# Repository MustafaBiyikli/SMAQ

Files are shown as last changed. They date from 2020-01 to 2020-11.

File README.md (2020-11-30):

## Smart monitoring of air quality with SMAQ
<p align="center">
    <a href="https://www.youtube.com/channel/UCAZxVj2a3wnd6SI2-zsWK3Q">
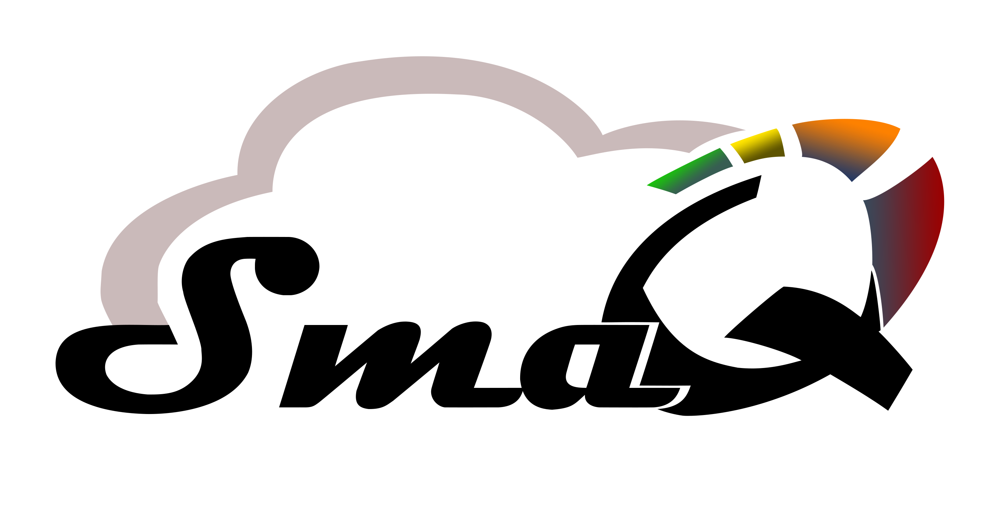
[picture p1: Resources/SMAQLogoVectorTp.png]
        
    </a>
</p>

SMAQ is designed to monitor the air quality in your chosen environment. The sampling rate can be adjusted from 1Hz to 10Hz. The ```./Software/Real-Time``` repo handles all low-level I2C communications and transmits the data via UDP (over port 65000) in real time as the data is sampled - to a JavaScript UDP receiver.
The UDP receiver places the data in a csv file which is then used to populate live DyGraphs and dashboard gauges for each parameter. The data is stored up to a week and follows a ring-buffer logic afterwards (storage time can be modified depending on the available disk space & user preference).
An express WebApp is launched from ```./Software/Website``` repo on port 8000 and can be accessed via url "ipofRaspberryPi:8000" within the same network.

- SMAQ is able to:
    - Sense:
        - Temperature: <b>-45 to 80 °C</b>
        - Pressure: <b>300 to 1250 hPa</b>
        - Humidity: <b>0 to 100 %</b>
        - Ambient Light: <b>0.25 to 16K lux</b>
        - Proximity: <b>1 to 200 mm</b>
        - Sound Levels: <b>0 to 100 %</b>
        - Carbon Monoxide: <b>1 to 1000 ppm</b>
        - Nitrogen Dioxide: <b>0.05 to 10 ppm</b>
        - Ammonia: <b>1 to 500 ppm</b>
    - Show the current conditions in your chosen environment with gauges
    - Store data up to a week, autozoom to 1wk | 5d | 3d | 24hr | 12 hr | 6hr | 1hr on WebApp
    - Send you immediate alerts via Email / Mobile Notifications and LEDs
    - Auto-remove your alerts when they are outdated
    - Output API data in JSON format
    - Display current conditions on an OLED display triggered by proximity
    
## PCB Design
The design files are in sub-directory ```./Hardware```
<p align="center">
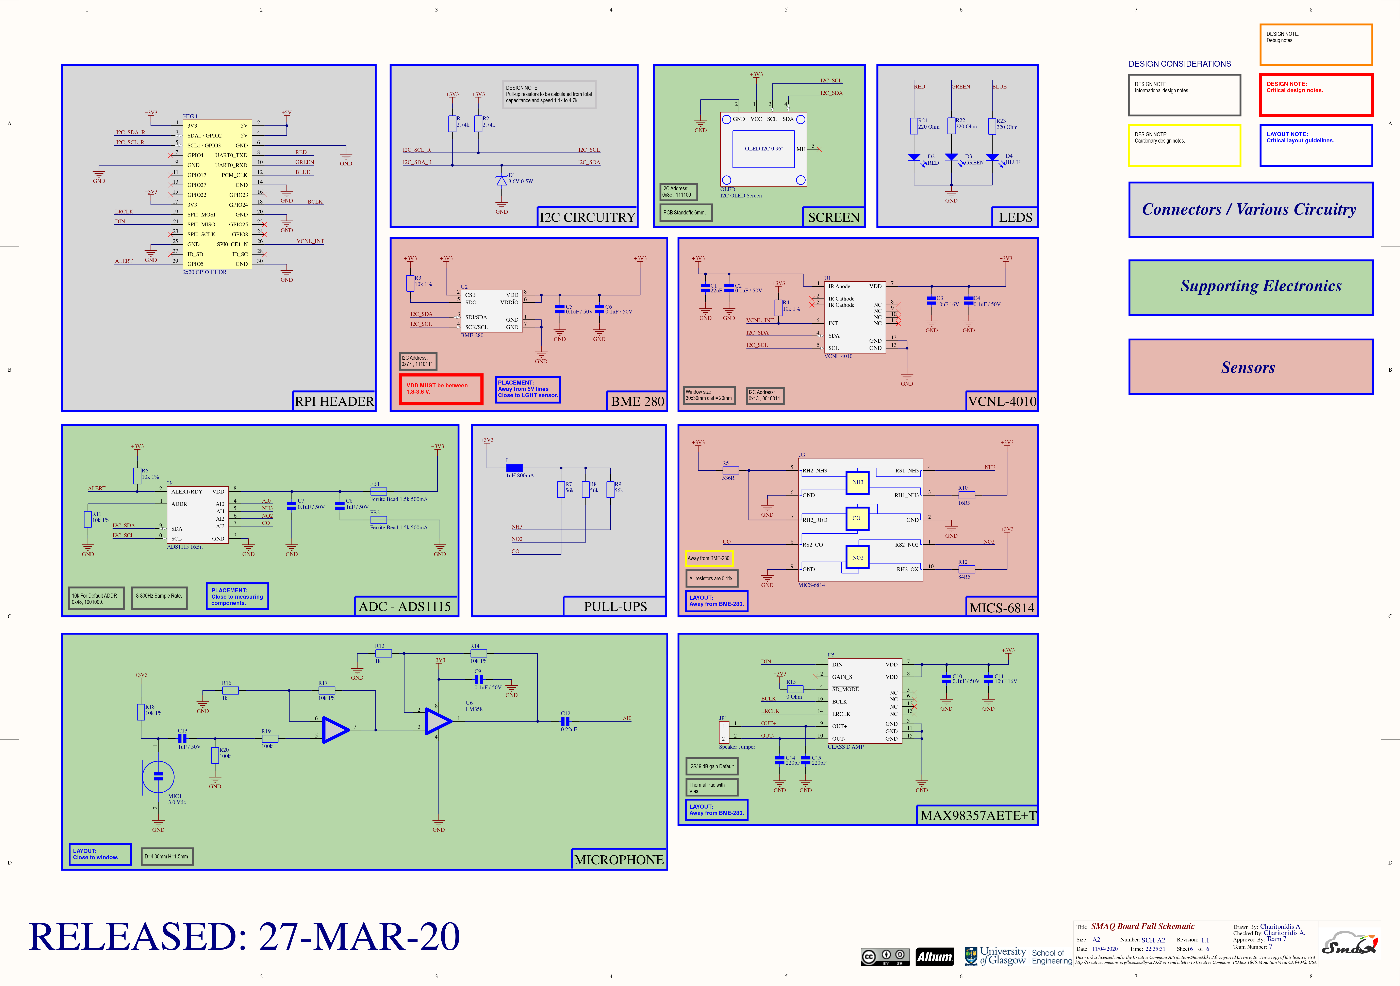
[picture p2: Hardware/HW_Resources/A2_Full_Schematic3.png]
    
</p>

## Pre-requisites
These are the packages required by SMAQ software, you need to have them installed on your raspberry Pi. They can be installed by running ```sudo apt-get install <package_name>```
```
gcc g++
cmake
git
npm
nodejs
```
Additionally, for receiving your alerts via email, you will need a <b>mailtrap</b> account for development and a <b>SendGrid</b> account for production. You will need to create your own ```config.env``` file and provide your keys. See ```./Software/Website/example-config.env.txt``` for a template.

## Building and running a demo
Clone and build the project with CMake
```
git clone https://github.com/MustafaBiyikli/SMAQ.git
cd SMAQ/Software/Real-Time
cmake .
make
```
Cmake will automatically check the I2C communication and run the necesarry tests when building the project. Test your harware by running a test.
```
./demo
```

This will start printing the sensor data onto your terminal. Press ```Enter``` to stop execution.

## Running the full WebApp
Start the cpp udp_transmitter in ```./Software/Real-Time``` as a background process:
```
./udp_transmit &
```

Then cd into ```../Website``` and run:
```
npm install
```

This will install the necessary NodeJS packages for the WebApp. Then, udp_receive.js and app.js needs to run as background processes. To do so, run the app in <b>production mode</b>:
```
npm run start:prod &
```
or:
```
node udp_receive.js &
node app.js &
```
You can now visit your SMAQ WebApp on url: "ipofRaspberryPi:8000"

## Killing the processes
To stop the background process, find their PIDs by:
```
ps ax
```
and kill each process by:

```
kill -HUP <PID>
```

## Viewing the WebApp without SMAQ
You can still view the WebApp without building the harware (using fake data), having cloned SMAQ into your local directory, you will need to start the app in <b>development mode</b>:
```
cd SMAQ/Software/Website
npm install
npm run start:dev &
```
or:
```
cd SMAQ/Software/Website
npm install
node fakeDataGenerator.js &
node app.js &
```
Killing the process follows the same logic as <b>Killing the process</b>

## Hardware - Main Components 

<p>
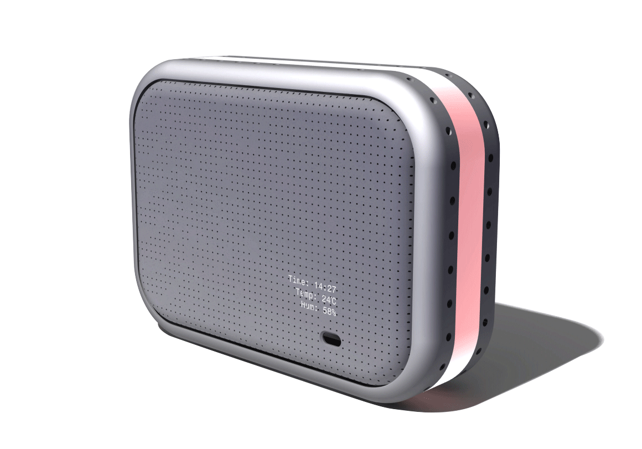
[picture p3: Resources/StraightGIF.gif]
    
</p>

See ```./Resources``` for packaging ideas and ```./Hardware``` for full details.

-   Raspberry Pi 3 Model B
-   PCB including:
    -   BME280 (Temperature, Pressure and Humidity Sensor)
    -   VCLN4010 (Proximity Sensor)
    -   SSH1106 (OLED Screen)
    -   MICS6814 (Gas Sensor)
    -   ADS1115 (ADC)
- 3D-printed casing and LED pipes

## Developers

<p align="center">
    <a href="https://github.com/Alexandros-Charitonidis">
        
    </a>
    &nbsp;  &nbsp;  &nbsp;  
    <a href="https://github.com/MustafaBiyikli">
        
    </a>
    &nbsp;  &nbsp;  &nbsp;  
    <a href="https://github.com/KasiaLenard">
        
    </a>
</p>

## Hosted Website

Vist SMAQ WebApp on: <b>https://team7smaq.github.io</b>
* Data you see here is randomly generated up to 1 minute as it is in development, however, the working principle is the same. You can have an idea of how SMAQ works without having to clone our repository.

## Introduction Video
<b>https://www.youtube.com/watch?v=mtV0Hn8jBWQ</b>

## Follow us on Social Media

<p align="center">
    <a href="https://www.facebook.com/SMAQ-Smart-Monitoring-of-Air-Quality-101030311565670">
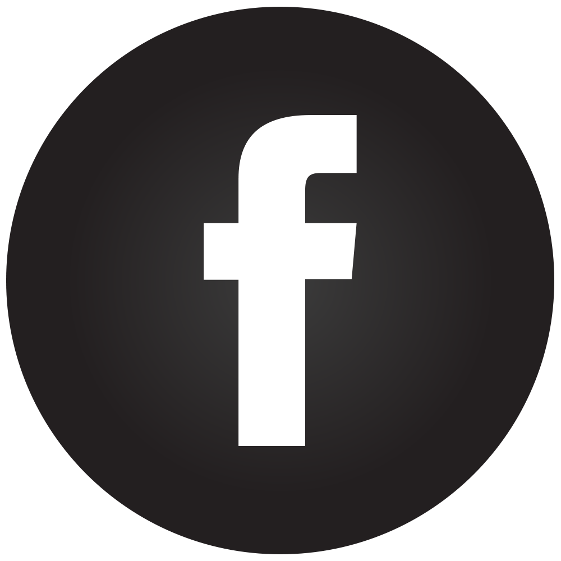
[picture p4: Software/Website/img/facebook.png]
        
    </a>
    &nbsp;  &nbsp;  &nbsp;  
    <a href="https://www.instagram.com/smaq_smart/">
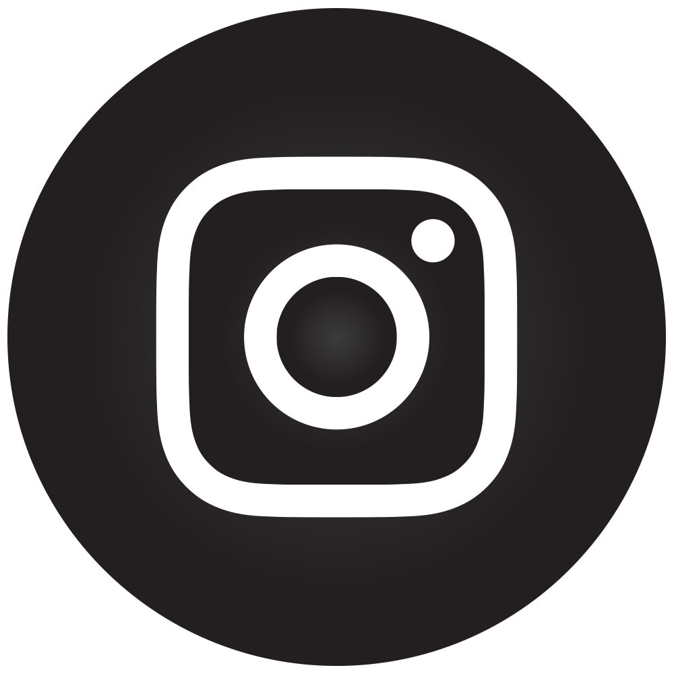
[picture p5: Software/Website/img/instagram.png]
        
    </a>
    &nbsp;  &nbsp;  &nbsp;  
    <a href="https://twitter.com/SMAQ82411071">
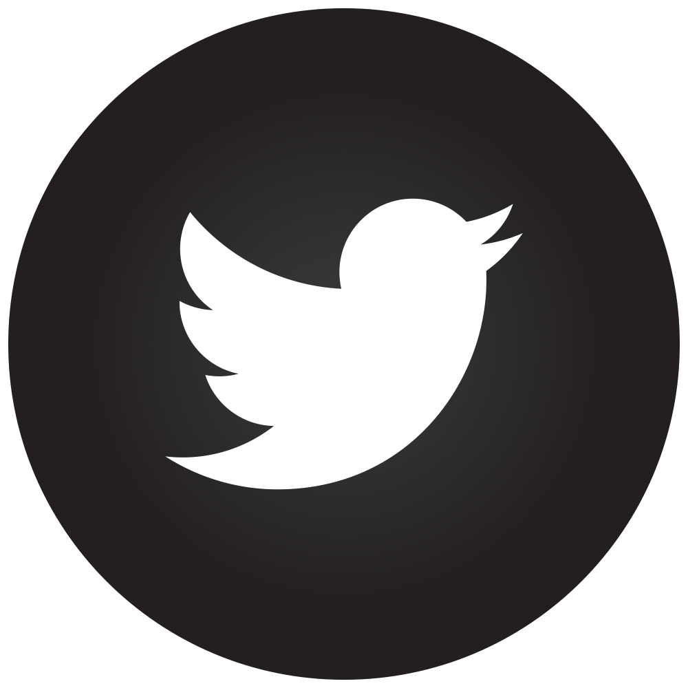
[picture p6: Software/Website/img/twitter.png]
        
    </a>
    &nbsp;  &nbsp;  &nbsp;  
    <a href="https://www.youtube.com/channel/UCAZxVj2a3wnd6SI2-zsWK3Q">
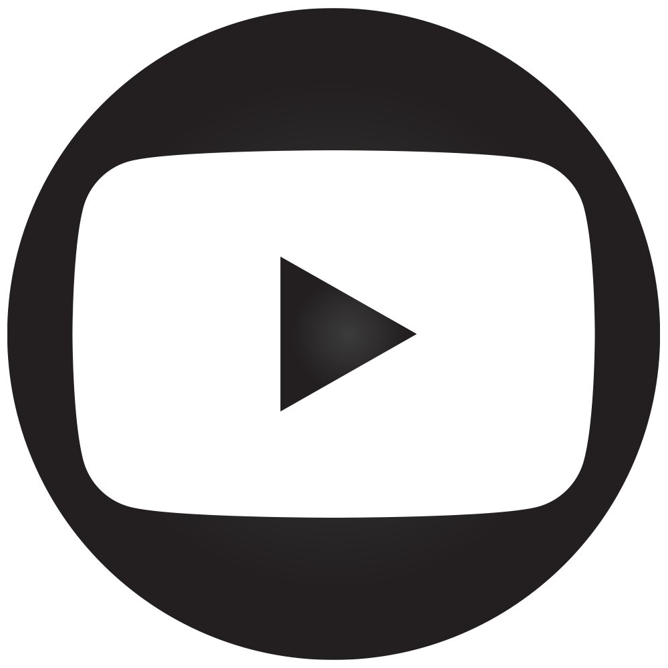
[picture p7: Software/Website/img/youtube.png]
        
    </a>
</p>

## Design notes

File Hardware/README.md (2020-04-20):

# Hardware Section
#### From this list you can navigate through different files needed for the reproduction SMAQ Board
* [3D Files](https://github.com/MustafaBiyikli/SMAQ/tree/master/Hardware/3D%20Files) 
|This is where you can find the STEP file and a 3DPDF of our board.
* [Board Assembly](https://github.com/MustafaBiyikli/SMAQ/tree/master/Hardware/Board%20Assembly) 
|Any info regarding Mechanical, BOM and Assembly can be found here.
* [HW_Resources](https://github.com/MustafaBiyikli/SMAQ/tree/master/Hardware/HW_Resources) 
|Various images and graphics.
* [PCB Manufacturing](https://github.com/MustafaBiyikli/SMAQ/tree/master/Hardware/PCB%20Manufacturing)
|This folder contains the Gerber output and Drill info and is ready for production.  
* [Source Files](https://github.com/MustafaBiyikli/SMAQ/tree/master/Hardware/Source%20Files)
| Custom made Libraries, Schematics and PCB documents made with Altium Designer 20.0.13.
* [Schematics](https://github.com/MustafaBiyikli/SMAQ/tree/master/Hardware/Schematics)
|A4 and A2 Schematics in Dynamic PDF Format are included here.

### You can have a look at the files above or follow the [full board design](https://github.com/MustafaBiyikli/SMAQ/blob/master/Hardware/Hardware-Documentation.pdf) documentation where all the above information is gathered in one place

## The design of the PCB
The Pcb design process is discussed below in summary, explaining vital choices that are made and the component selection process.
Since the idea of constructing an Air Quality Monitoring was established a thorough search on available technologies was conducted to find the most compatible sensors available. The main focus was on finding robust accurate and up to date Environmental sensors with regards to Temperature sensing and Hazardous gas detection.
Sensors from high-end companies like Bosch and Sensortech were chosen. To add extra capabilities to our product, a proximity and light intensity sensor from VISHAY was chosen. All Sensors except the Gas Sensor are digital and accommodate the I2C protocol. Lastly, an OLED screen, a class D audio amplifier and an analogue microphone circuitry were realised to accommodate user interaction facilities.

The library for the parts used in the SMAQ are Custom made to fit the needs of our product. All parts were carefully chosen according to recommendations from the sensor companies and to the highest possible quality. Companies like Panasonic, Kemet, TDK and Texas Instruments were considered in our design.

A list of all components can be found [here](https://github.com/MustafaBiyikli/SMAQ/blob/master/Hardware/Board%20Assembly/SMAQ-Board_DesignBOM.pdf). The function of our board is to regularly scan the environmental conditions of a room (Temperature, Pressure, Humidity, various Gases etc.) and output them to a website and when prompted — to the screen. Therefore, a single double-sided PCB was accomplished, and schematics were made with appropriate connections and protection circuits. The software used for the design process is Altium Designer.

Here is the [PCB layout](https://github.com/MustafaBiyikli/SMAQ/blob/master/Hardware/HW_Resources/UofG-Board-etching-SMAQ.pdf) sent to the services to be printed.
<p align="center">
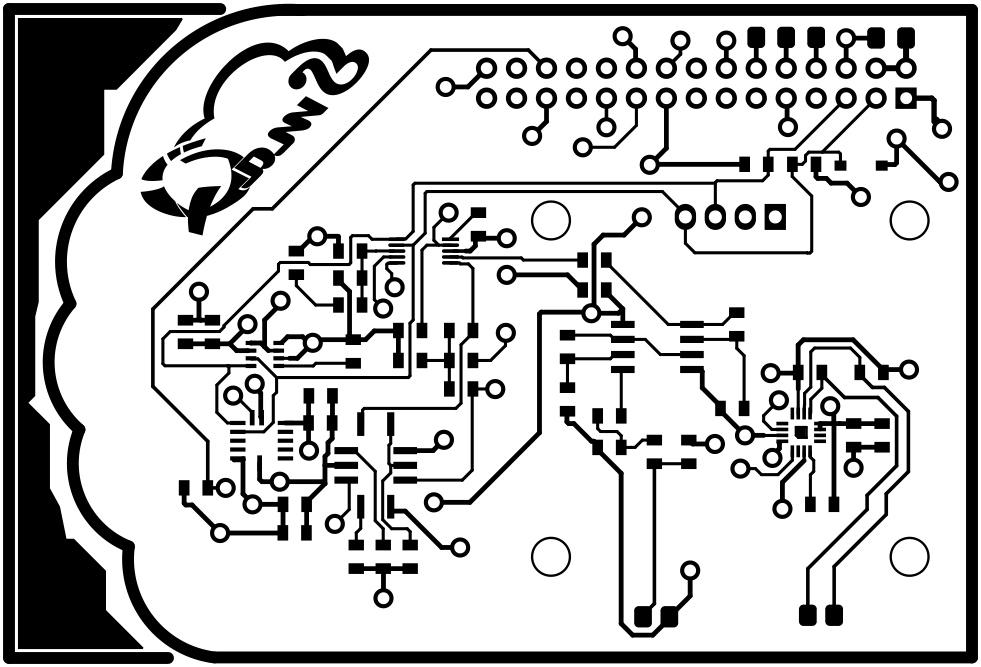
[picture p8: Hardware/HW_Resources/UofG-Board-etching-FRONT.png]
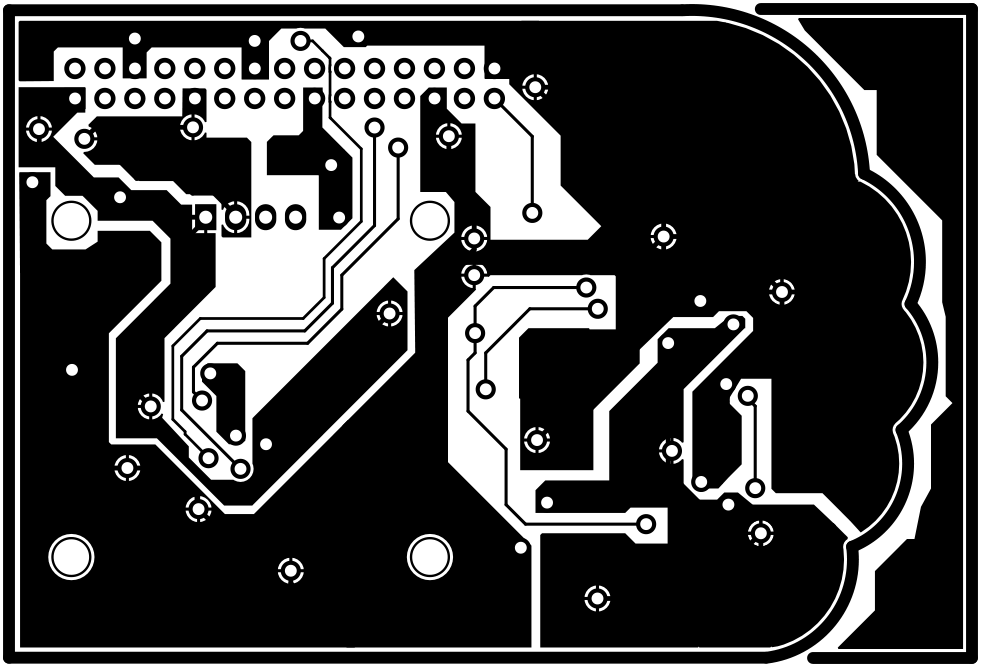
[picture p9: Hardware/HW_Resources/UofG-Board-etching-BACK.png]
  
</p>

And a photorealistic model of the final board.

<p align="center">
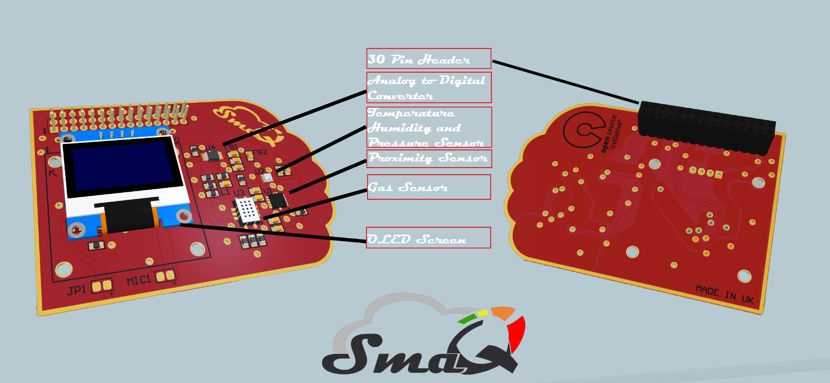
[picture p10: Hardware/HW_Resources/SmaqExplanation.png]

</p>

After ordering the components, a small prototype was made with some components to test them. Due to the nature of the small packages that were chosen, a full-scale prototype was not applicable.

<p align="center">

</p>

Also, some images showing the manufacturing process of our board can be found in this section.

---
The fabrication process of the PCB was done through the Tech Services of the School Of Engineering at the University of Glasgow.

<p align="center">
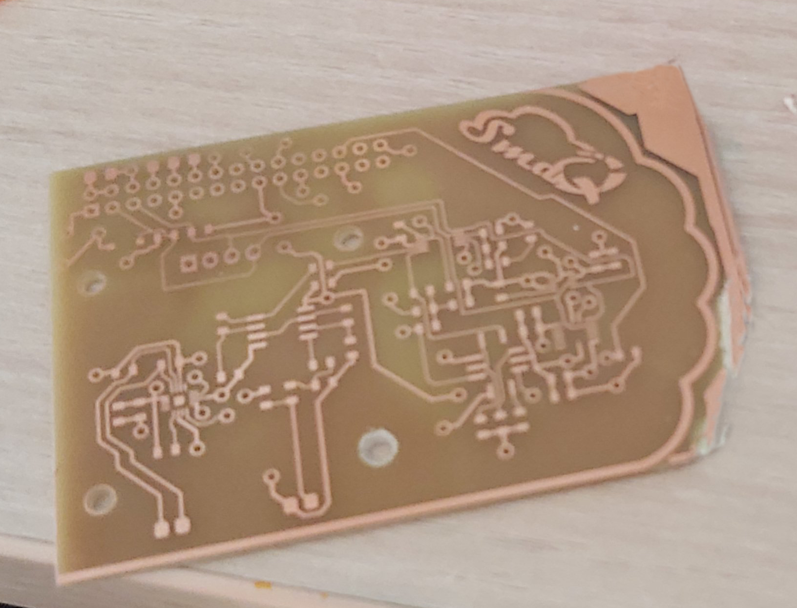
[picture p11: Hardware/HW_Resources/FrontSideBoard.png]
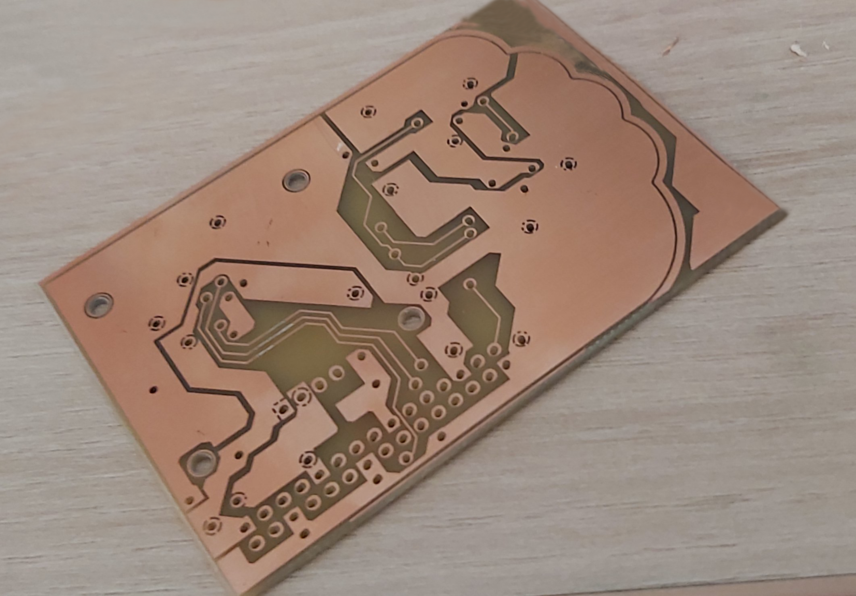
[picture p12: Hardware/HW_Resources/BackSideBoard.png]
  
</p>

After the board was etched a surface clean up and board outline shaping commenced resulting in the finished shape of the board.

<p align="center">
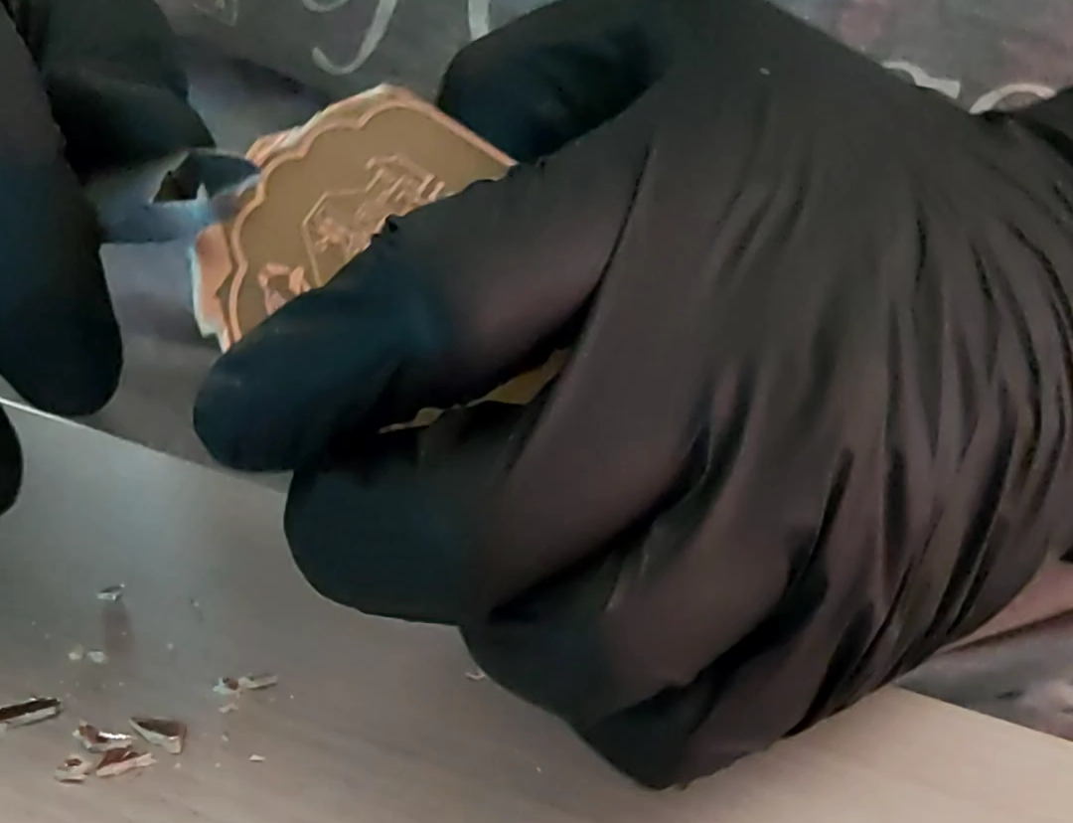
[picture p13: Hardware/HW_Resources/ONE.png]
 
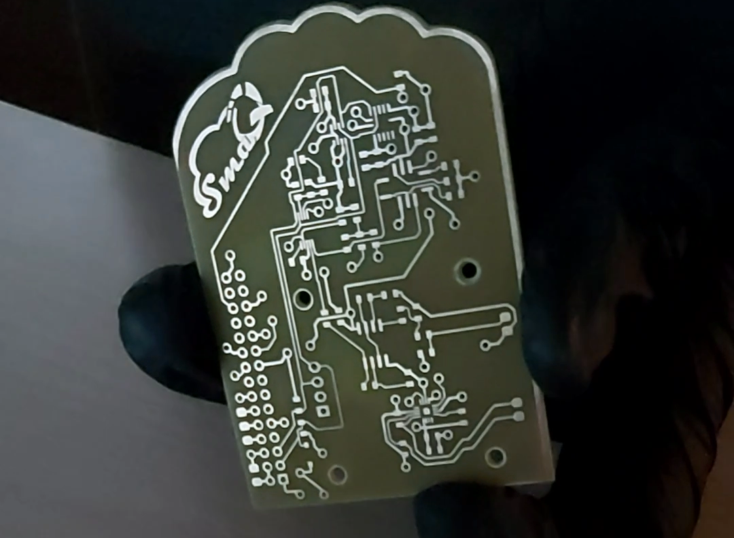
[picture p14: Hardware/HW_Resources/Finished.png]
  
</p>

In order to protect the board from oxidation and help the component soldering a UV curable solder mask was applied. Using transparencies of the top and bottom layout, approximately 4ml of UV solder resist was dispensed on each side. After curing the paint for 20 seconds, the transparencies were removed, and the uncured pattern was cleaned. Afterwards, the solder mask was fully cured under the UV lamp for three minutes.

<p align="center">

</p>

To fully ensure the protection of the board, exposed pads and of the etched logo, a coat of tin (5μm) was applied on top of the exposed copper.
This was done through electroless tinning. 

<p align="center">
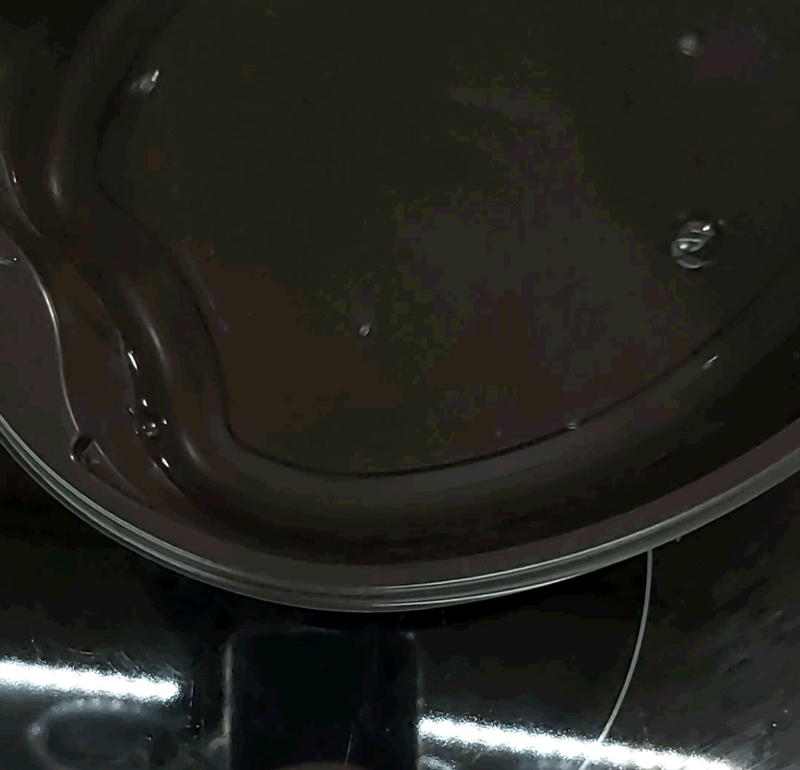
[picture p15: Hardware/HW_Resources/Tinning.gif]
 
 
</p>

<p>
 
</p>

All processes were done in controlled and well-ventilated areas using appropriate PPE.

The soldering process involved the use of a micro-soldering iron, hot air station, microscope and no-clean flux. 

ESD safe procedures were followed using appropriate equipment and proper grounding. To clean the board a 99.9% Isopropyl Alcohol was used. The solder used is 0.25mm Leaded 60/40 Rosin-free while a straight and chisel tip was used on different areas. 
<br/>
<br/>
<br/>
<br/>
<br/>
<br/>
<br/>
<br/>
<br/>
<br/>
<br/>

---
#### The board after the manufacturing procedure with the screen assembled on 3mm standoffs fitted on top of the Raspberry Pi.
<p align="center">
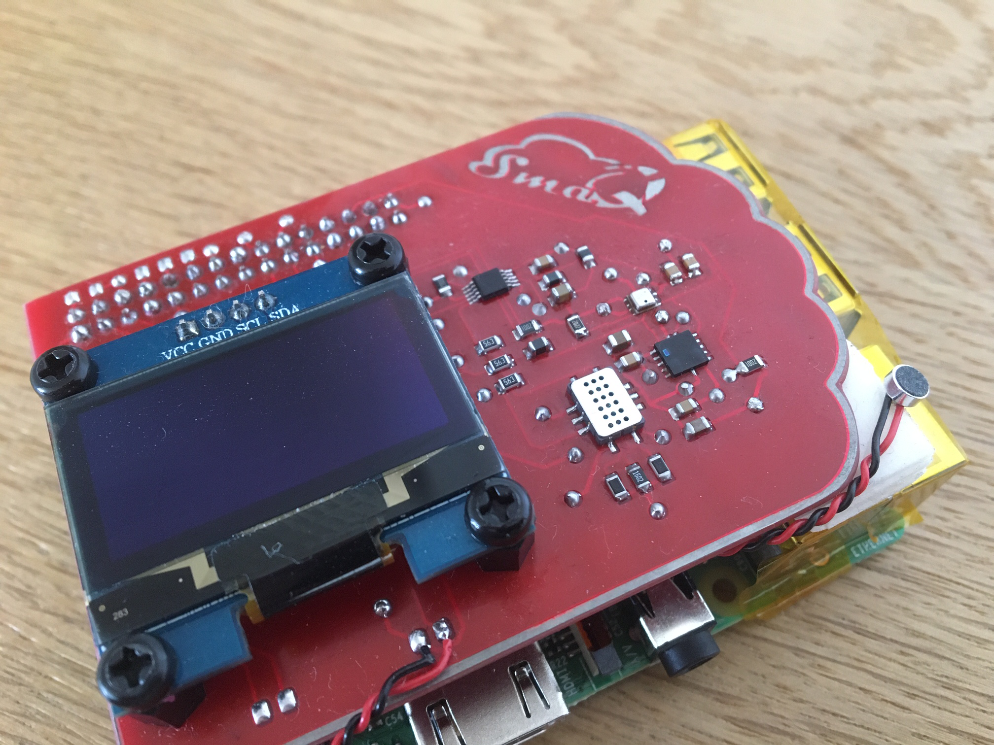
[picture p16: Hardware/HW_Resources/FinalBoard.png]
 
</p>

## Casing
All printer ready CAD files and pdf drawings can be found under ```./Casing``` directory. We were unable to manufacture the casing due to unforseen events (COVID-19). Therefore, its ergonomics in real life are yet to be tested.
<p align="center">
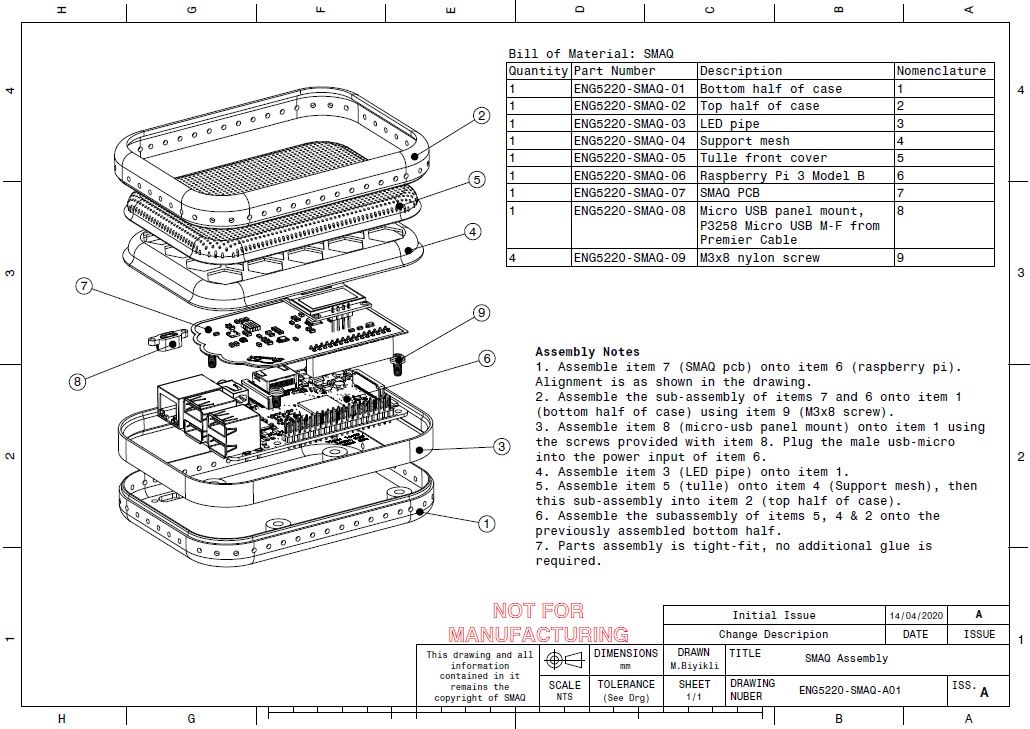
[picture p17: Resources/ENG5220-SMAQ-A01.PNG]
  
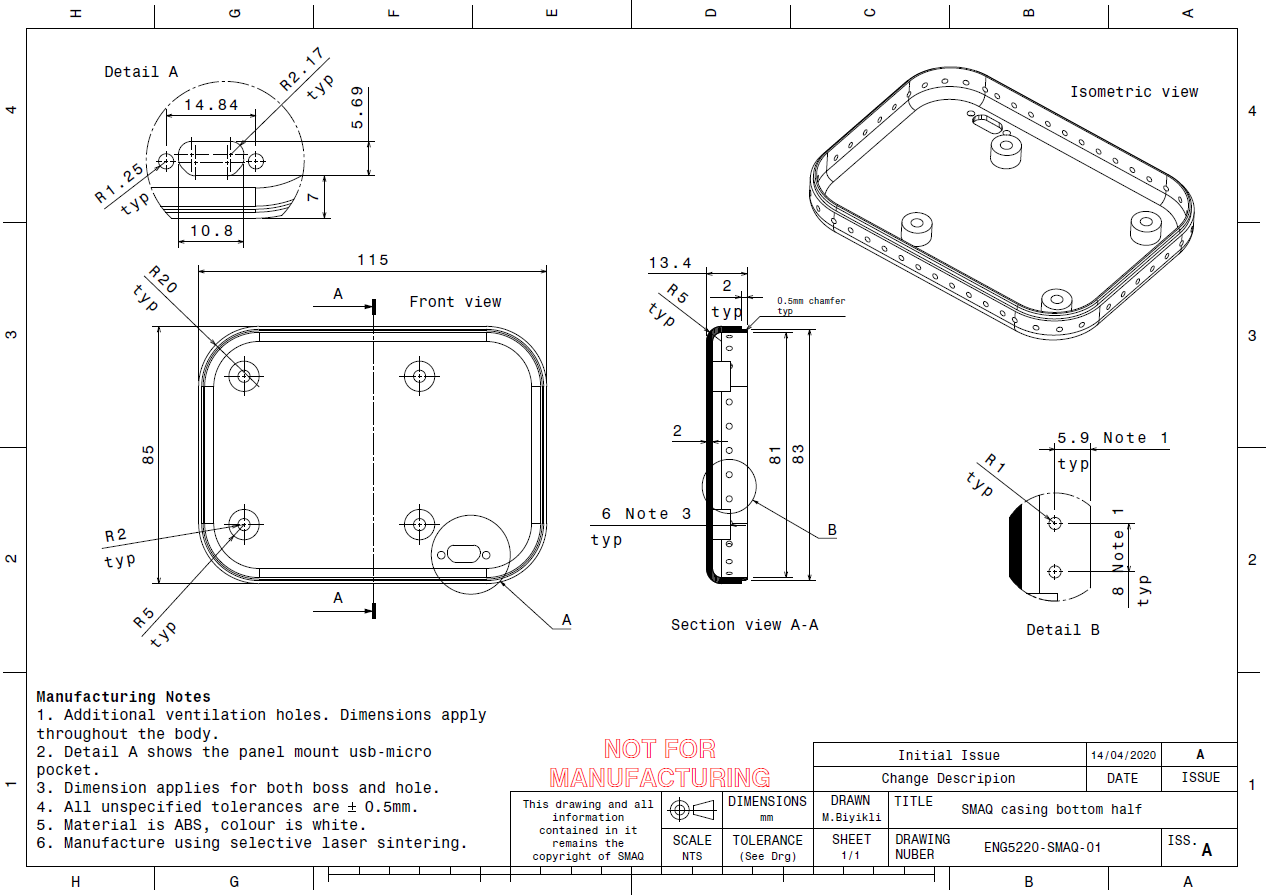
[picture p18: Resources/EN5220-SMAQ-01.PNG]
  
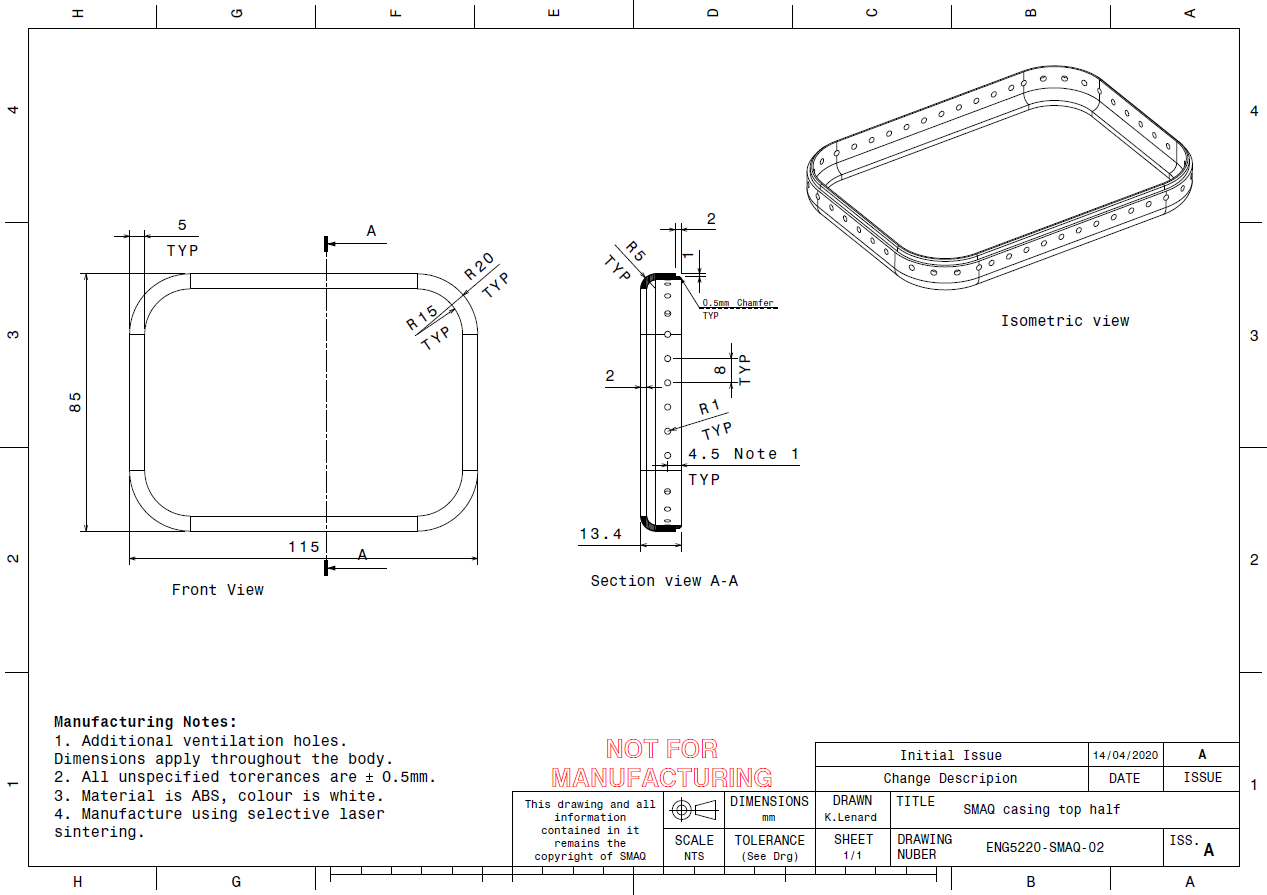
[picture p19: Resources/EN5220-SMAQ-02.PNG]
  
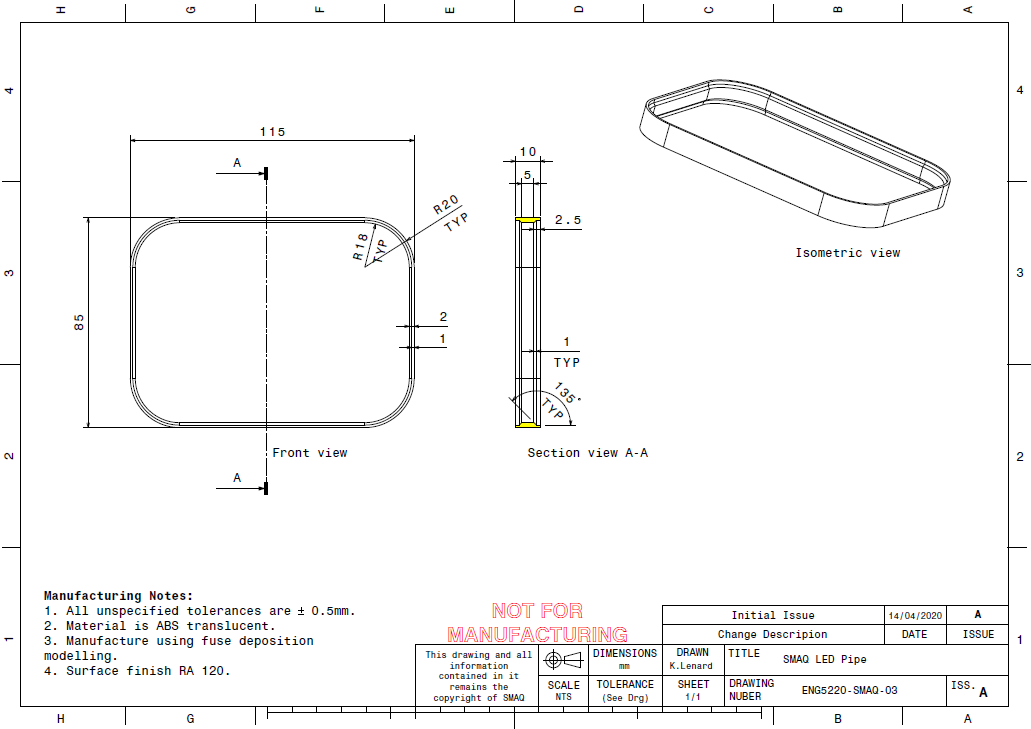
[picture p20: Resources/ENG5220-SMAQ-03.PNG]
  
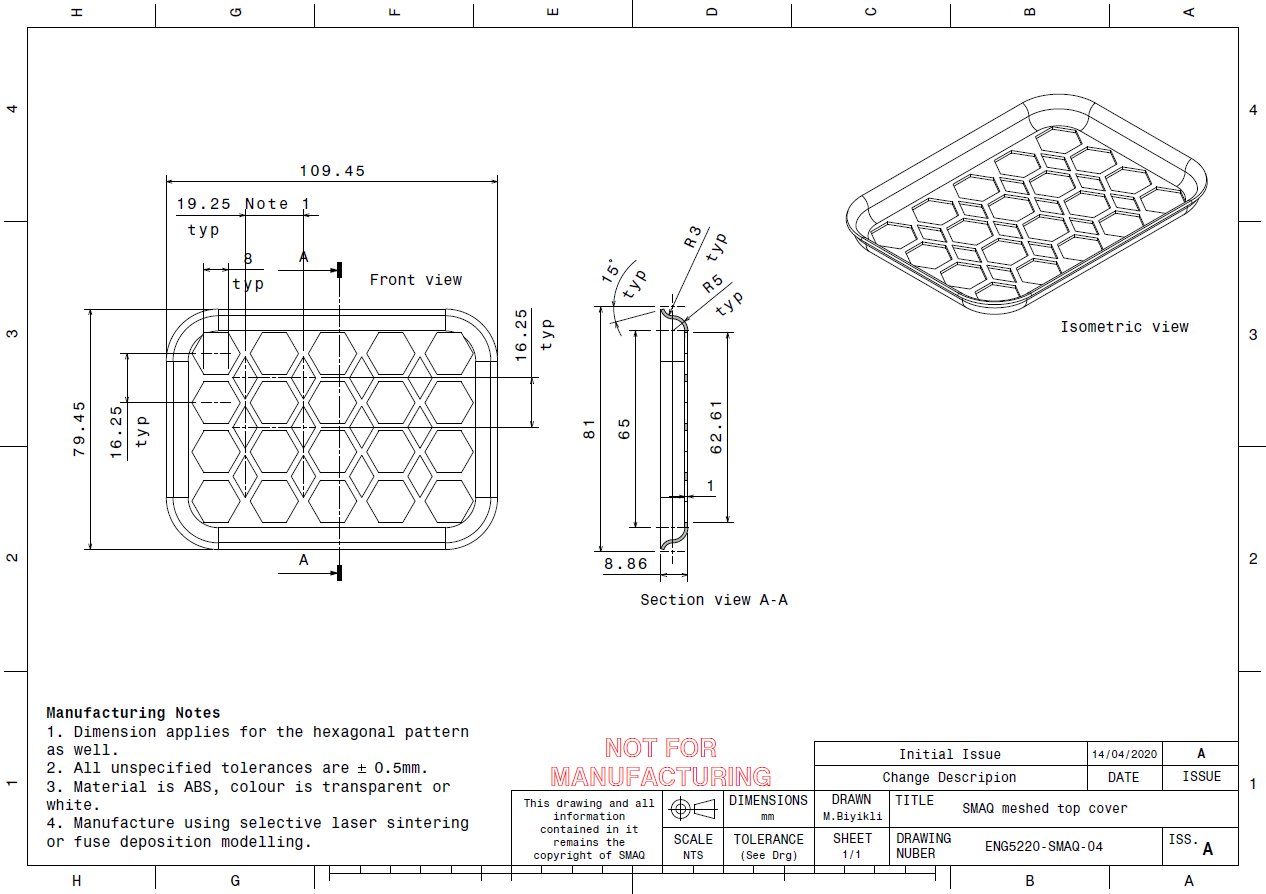
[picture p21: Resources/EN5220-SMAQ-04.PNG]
  
</p>

<br />This work is licensed under a <a rel="license" href="http://creativecommons.org/licenses/by-sa/3.0/">Creative Commons Attribution-ShareAlike 3.0 Unported License</a>.

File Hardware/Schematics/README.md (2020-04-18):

### An [A2 copy](https://github.com/MustafaBiyikli/SMAQ/blob/master/Hardware/Schematics/Schematics-Full-A2.PDF) of the schematics and a printable [A4 version](https://github.com/MustafaBiyikli/SMAQ/blob/master/Hardware/Schematics/Schematics-Printable-A4.PDF) can be found here.

You can dynamically search and acquire all necessary information about components on our PDFs without the need for any special software.

<p align="center">
        
    </a>
</p>

And a small explanation of how our PDFs can be used to troubleshoot the board and identify components from the board.

<p align="center">
        
    </a>
</p>

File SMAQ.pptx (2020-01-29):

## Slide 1

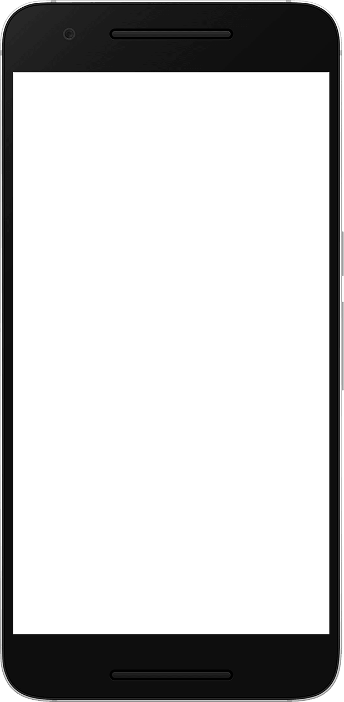
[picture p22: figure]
Image result for android phone template

101 kPa

22°C

47%

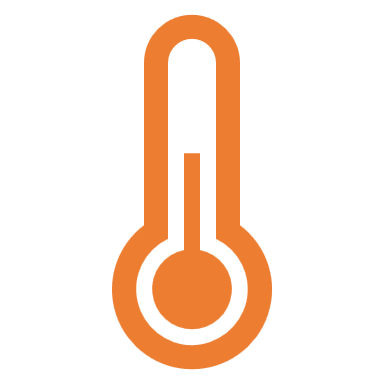
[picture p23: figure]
Thermometer
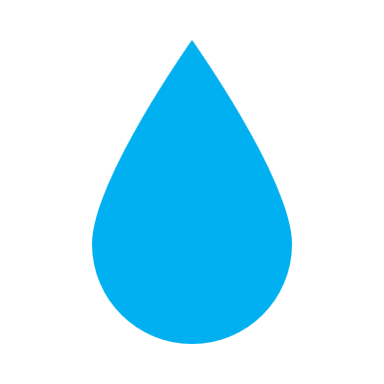
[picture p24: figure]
Water

78%

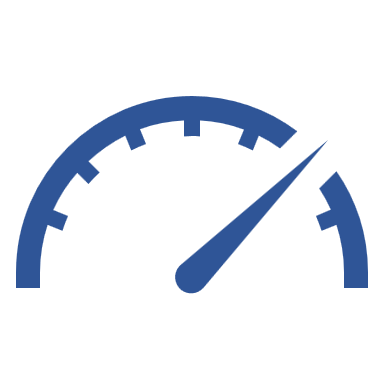
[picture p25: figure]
Gauge
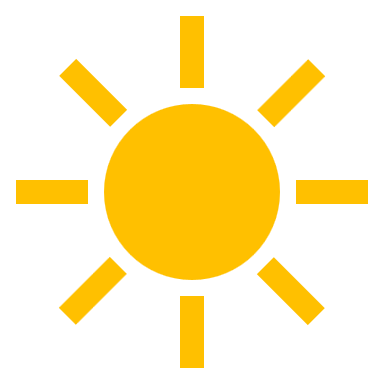
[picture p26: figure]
Sun

123ppm

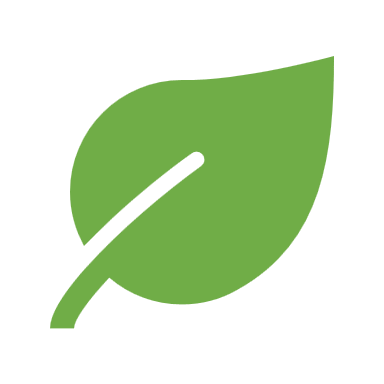
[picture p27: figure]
Leaf

35dB

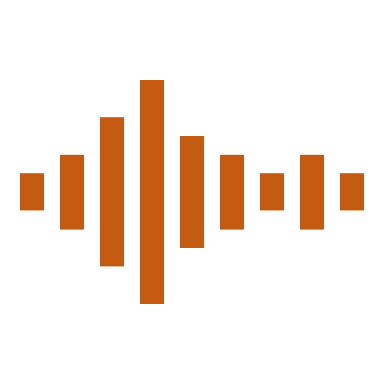
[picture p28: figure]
Voice
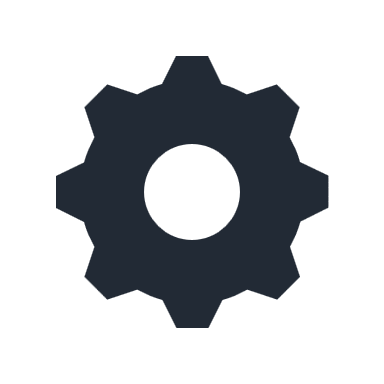
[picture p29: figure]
Single gear
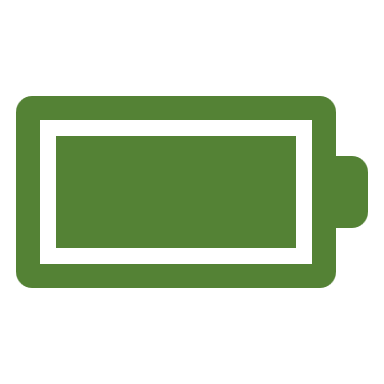
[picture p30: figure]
Full battery
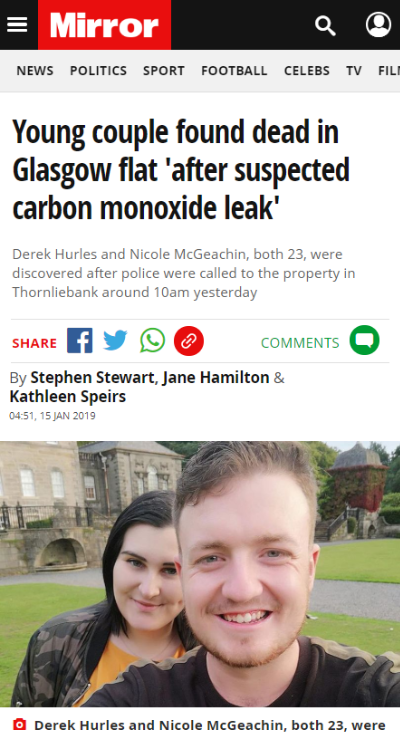
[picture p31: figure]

Smart Monitoring of Air Quality

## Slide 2


Why SMAQ?
Temperature
Humidity
Pressure
Air Quality (CO, NO2)
Light Intensity
Noise Level


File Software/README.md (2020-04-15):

Software related to:
- Real-Time & Sampling: see ```./Real-Time```
- WebApp & Server: see ```./Website```
- Android native app: see ```./Android-App```

## How it works


1. You will need a raspberry Pi with configured network settings. Both WiFi and Ethernet can be used. SMAQ will keep your previous data even if your pi gets disconnected.

2. C++ handles all low level I2C communications with SMAQ. No timers are used anywhere in the code. Samples are only  taken when the data is ready, <b>i.e:</b> when a hardware interrupt is fired. This assures a reliable and constant sampling rate which can be adjusted from 1 to 10 Hz.

3. Collected samples are placed in a buffer and transmitted to NodeJS over UDP port 65000.

4. Once the data is received in the backend, it is handled by a javascript data handler, ```./Website/udp_receive.js``` which stores the incoming data in CSV files.

5. Frontend javascript reads the data as it comes using jQuery.ajax and plots it on dashboard gauges allowing users to easily view the current parameters in their chosen environment. 
<p align="center">
  
  
</p>

6. SMAQ will store data up to a week in CSV files and use these to plot a Dygraph. Once a week has passed, the data will follow a ring buffer logic. Oldest data will be removed and the newest will be inserted. Users can enable auto-zoom or interact with the plots manually for each parameter.
<p align="center">
  
  
</p>

7. Warnings, errors, information and success related data is displayed on an alerts page with the date and time of the event. The users may subscribe to their SMAQ and receive real & immediate emails through SendGrid in production <b>i.e:</b> ```npm run start:prod```. Or developers may test the features of the WebApp using mailtrap on development <b>i.e:</b> ```npm run start:dev```
<p align="center">
  
  
</p>

8. Users are able to subscribe & unsubscribe to their SMAQs at any time they desire. Up to 5 users may subscribe to a SMAQ. All subscribed users will receive the alert emails.
<p align="center">
  
  
</p>

9. Users are able to view SMAQ related information and access the source code through our WebApp and Android App.
<p align="center">
  
  
</p>

10. Users are able to report any issues to us, developers, using the Contact page on the WebApp. Production limits these emails to valid emails only, however, development accepts both valid & invalid email addresses.
<p align="center">
  
  
</p>

11. Your raspberry Pi will act as the server and host your WebApp over TCP/IP on port 8000. Once your WebApp is up and running, you can use your mobile app to interact with your SMAQ as well.

## How to start your WebApp
As explained in the main page, given you have the pre-requisites installed on your raspberry Pi you will need to clone this repository, build the files, install the npm packages and start your server.

### Run in development
Running in development does not require any hardware. You can test the WebApp and its features using a fake data generator. This will limit the data storage to 60 seconds and direct your emails to <b>mailtrap</b> if you have created an account and added your details to a ```config.env``` file in ```./Website```. To run:
```
git clone https://github.com/MustafaBiyikli/SMAQ.git
cd Software/Website
npm install
npm run start:dev
```

### Run in production
Running in production requires the hardware as it fires up the ```udp_receiver.js``` which is listening for c++ udp_transmitter over port 65000. This will give you full week of data storage and send real emails to your inbox. You will still need to set a <b>SendGrid</b> account and create a ```config.env``` file in ```./Website``` with your account details. To run:
```
git clone https://github.com/MustafaBiyikli/SMAQ.git
cd Software/Real-Time
cmake .
make
./udp_transmit &
cd ../Website
npm install
npm run start:prod
```

## How to run your Android Native App
In order to enhance user experience on mobile devices (Android platform) we have developed a native mobile app. Pairing the app with your SMAQ is done by providing the app with the ip address of your Raspberry Pi. <This may be automated in future realeases>
Use Android Studio to build the project and run the app on your Android device.

1. Launch Android Studio
2. File > Open ```<directory_you_cloned>/SMAQ/Software/Android-App```
3. Android Studio should automatically build the project. If not: Build > Make Project
4. Connect your device and run the app!

<b>Note: Minimum API 26: Android 8.0 (Oreo) required!</b>

### Using the Android App
<ul>
  <li> The mobile app follows exactly the same logic as the WebApp with an additional step of pairing it to your SMAQ. You will need to type the ip address of your SMAQ. The app will check if the IP address given is correct and if it is, will bind to your SMAQ and show    your dashboard. 
  </li>
  <li>See <b>How it works</b> section for demonstrations.</li>
</ul>

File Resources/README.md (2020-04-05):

# A mockup for packaging

<p align="center">
    
</p>

<p align="left">
    
</p>

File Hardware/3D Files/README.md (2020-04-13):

## 3D Step file of the board and a 3D pdf are included in this folder
The 3DPDF only works when downloaded and opened through Acrobat Reader. You need to press yes on the PDF prompt about the "Certificate" and press the red questionmark on the top left corner to enable 3D content
on the PDF.
<p align="center">
        
    </a>
</p>

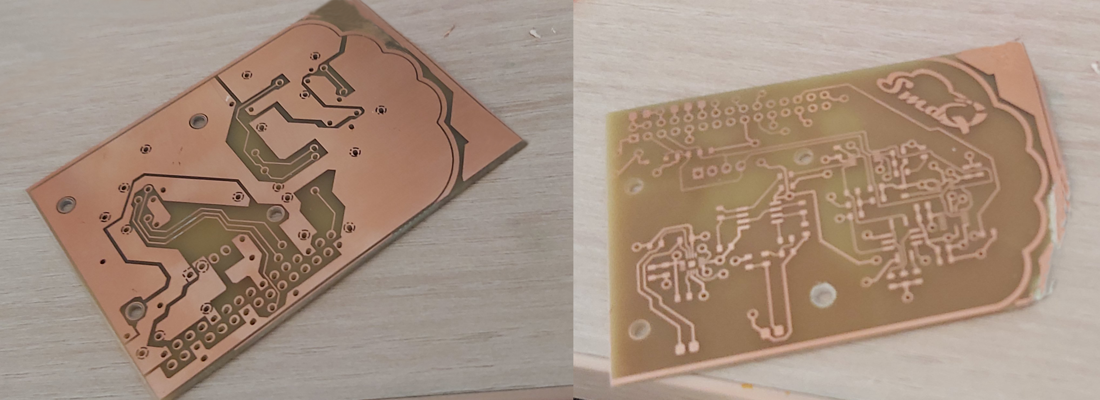
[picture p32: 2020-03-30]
Hardware/HW_Resources/FrontandBackSideBoard.png

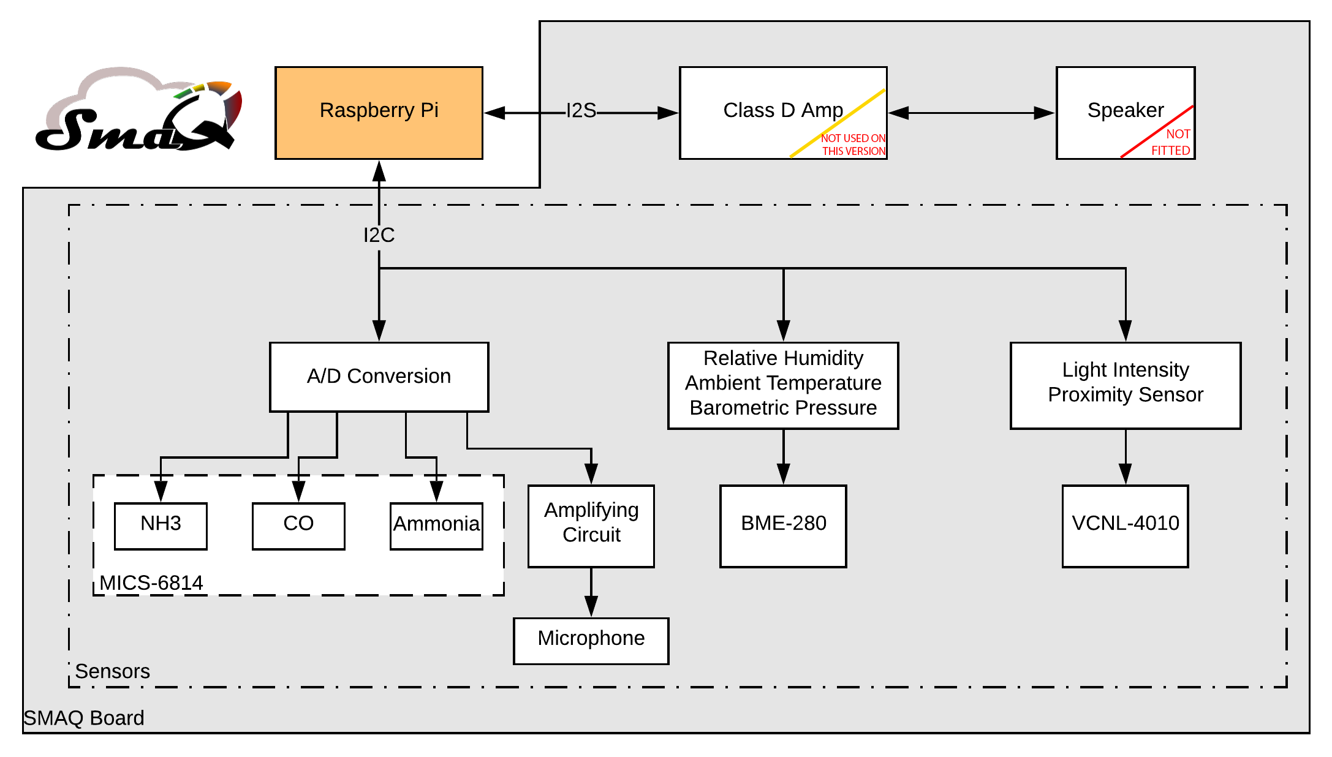
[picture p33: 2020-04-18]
Hardware/HW_Resources/BlockDiagram.png

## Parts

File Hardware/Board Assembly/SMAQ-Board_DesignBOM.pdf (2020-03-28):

| Created by SMAQ | | | | | | Smart Monitoring of Air Quality Board Design
Component list | Bill of Materials Smart Monitoring of Air Quality SMAQ
Source Data From: | SMAQ-Board_Design.BomDoc | Contact: Alexandros Charitonidis | Generated by:
Project: | SMAQ-Board_Design.PrjPcb
Variant: | None
| Report Date: | 15/02/2020 | 20:02
Print Date: | 28-Mar-20 | 8:28:22 PM
# | Category 1 | Manufacturer 1 | Manufacturer Part Number 1 | Description | Quantity | Supplier 1 | Supplier Part Number

1 | Supplier Order Qty 1 | Supplier
Stock 1

Supplier
Unit Price
1

Supplier
Subtotal 1

Supplier
Currency 1
1 | Amplifiers - Op Amps, Buffer, Instrumentation | Texas Instruments | LM358DR | IC OPAMP GP 700KHZ 8SOIC | 1 | Mouser | 595-LM358DR | 1 | 10391 | 0.29 | 0.29 | GBP
2 | Amplifiers - Audio | Maxim | MAX98357AETE+T | IC AUDIO AMP CLASS D 16-TQFN | 1 | Mouser | MAX98357AETE+T 700- | 1 | 5567 | 1.82 | 1.82 | GBP
3 | Analog to Digital Converters (ADCs) | Texas Instruments | ADS1115IDGSR | IC ADC 16BIT 860SPS LP 10MSOP | 1 | Mouser | 595-ADS1115IDGSR | 1 | 13988 | 4.27 | 4.27 | GBP
4 | Sensors | AMPHENOL SGX SENSORTECH | MICS-6814 | SHUT HEIGHT GAGE(119.5MM) | 1 | Mouser | 523-MICS-6814 | 1 | 708 | 14.70 | 14.70 | GBP
5 | Pressure Sensors | Bosch | BME280 | Pressure, Temperature and Humidity Sensor Digital Output 1.8V 8-Pin LGA T/R | 1 | Mouser | 262-BME280 | 1 | 17744 | 2.89 | 2.89 | GBP
6 | Sensors | Vishay Semiconductors | VCNL4010-GS08 | SENS IR PROXIMITY AMB LT 12LLP | 1 | Mouser | 78-VCNL4010-GS08 | 1 | 15551 | 2.40 | 2.40 | GBP
7 | Chip SMD Resistors | Panasonic | ERJ-6GEY0R00V | RES SMD 0 OHM JUMPER 1/8W 0805 | 3 | Mouser | 667-ERJ-6GEY0R00V | | 17000 | 0.08 | 0.24 | GBP
8 | Chip SMD Resistors | Panasonic | ERJ-6ENF1003V | RES SMD 100K OHM 1% 1/8W 0805 | 2 | Mouser | 667-ERJ-6ENF1003V | 2 | 286752 | 0.08 | 0.15 | GBP
9 | Chip SMD Resistors | Panasonic | ERJ-6GEY0R00V | RES SMD 0 OHM JUMPER 1/8W 0805 | 1 | Mouser | 667-ERJ-6GEY0R00V | 1 | 788480 | 0.08 | 0.08 | GBP
10 | Chip SMD Resistors | Panasonic | ERA-6AED102V | Res Thin Film 0805 1K Ohm 0.5% 1/8W ±25ppm/°C Molded SMD SMD Punched Carrier T/R | 2 | Mouser | 667-ERA-6AED102V | 2 | 18196 | 0.18 | 0.36 | GBP
11 | Chip SMD Resistors | Panasonic | ERA-6AEB84R5V | RES SMD 84.5 OHM 0.1% 1/8W 0805 | 1 | Mouser | 667-ERA-6AEB84R5V | 1 | 6045 | 0.28 | 0.28 | GBP
12 | Chip SMD Resistors | Panasonic | ERA-6AEB2741V | Res Thick Film 0805 16.9 Ohm 1% 1/4W 300ppm/C Molded SMD Punched Carrier T/R | 1 | Mouser | 667-ERA-6AEB2741V | 1 | 5043 | 0.28 | 0.28 | GBP
13 | Chip SMD Resistors | Panasonic | ERA-6AEB563V | RES SMD 56K OHM 0.1% 1/8W 0805 | 3 | Mouser | 667-ERA-6AEB563V | 3 | 13309 | 0.28 | 0.84 | GBP
14 | Chip SMD Resistors | Panasonic | ERA6AEB5360V | RES SMD 536 OHM 0.1% 1/8W 0805 | 1 | Mouser | 667-ERA-6AEB5360V | 1 | 8172 | 0.28 | 0.28 | GBP
15 | Chip SMD Resistors | Yageo | AT0805FRE0710KL | RES SMD 10K OHM 1% 1/8W 0805 | 7 | Mouser | 603-AT0805FRE0710KL | 10 | 12701 | 0.25 | 2.49 | GBP
16 | Chip SMD Resistors | Panasonic | ERA6AEB2741V | Surface Mount Chip Resistor, Thin Film, AEC-Q200 ERA Series, 2.74 kohm, 125 mW, 0.1%, 100 V | 2 | Mouser | 667-ERA-6AEB2741V | 2 | 8588 | 0.28 | 0.56 | GBP
17 | Sensors | CUI Devices | CMC-4015-25L100 | 4.0 mm, Omnidirectional, Wire Leads, 3.0 Vdc, IP65 Rated, Electret Condenser Microphone | 1 | Mouser | 490-CMC-4015-25L100 | 1 | 481 | 1.94 | 1.94 | GBP
18 | Inductors | TDK | KLZ2012MHR1R0HTD25 | FIXED IND 1UH 800MA 130 MOHM SMD | 1 | Mouser | KLZ2012MHR1R0HTD 810- | 1 | 3633 | 0.24 | 0.24 | GBP
19 | Headers | Adafruit Industries | 2222 | GPIO FEMALE HEADER RASPBERRY PI | 1 | Mouser | 485-2222
20 | Inductors | TDK | MMZ2012Y152BT000 | Ferrite Beads Multi-Layer 1.5KOhm 25% 100MHz 500mA 400mOhm DCR 0805 | 2 | Mouser | 810-MMZ2012Y152BT000 | 2 | 110 | 0.09 | 0.17 | GBP
21 | Zener Diodes | Vishay | BZT52B3V6-E3-08 | Diode Zener Single 3.6V 2% 500mW 2-Pin SOD-123 T/R | 1 | Mouser | 78-BZT52B3V6-E3-08 | 1 | 29413 | 0.25 | 0.25 | GBP
22 | Ceramic Capacitors | Kyocera AVX | 08055A221F4T2A | T&R / COMMERCIAL CHIP | 2 | Mouser | 581-08055A221F4T2A | 2 | 6955 | 0.36 | 0.73 | GBP
23 | Ceramic Capacitors | Kyocera AVX | 08053C224J4Z2A | Multilayer Ceramic Capacitors MLCC -SMD/SMT 25V 0.22uF X7R 0805 5% AEC-Q200 | 1 | Mouser | 581-08053C224J4Z2A | 1 | 37020 | 0.15 | 0.15 | GBP
24 | Capacitors | Kyocera AVX | 08055C105JAT2A | Multilayer Ceramic Capacitors MLCC -SMD/SMT 25V 1.0uF X7R 0805 5% AEC-Q200 | 2 | Mouser | 581-08055C105JAT2A | 2 | 4264 | 0.39 | 0.77 | GBP
25 | Capacitors | Kyocera AVX | 0805YC106MAT2A | Multilayer Ceramic Capacitors MLCC -SMD/SMT 25V 10uF X7R 0805 5% AEC-Q200 | 2 | Mouser | 0805YC106MAT2A 581- | 2 | 1716 | 0.45 | 0.90 | GBP
26 | Ceramic Capacitors | Kyocera AVX | 08055C104JAT4A | CAP CER 0.1UF 50V X7R 0805 | 7 | Mouser | 581-08055C104JAT4A | 10 | 69837 | 0.12 | 1.16 | GBP
27 | Ceramic Capacitors | TDK | C2012JB1A226M085AC | CAP CER 22UF 10V JB 0805 | 1 | Mouser | C2012JB1A226M08C 810- | 1 | 10381 | 0.53 | 0.53 | GBP
| | | | | 50 | | | | 52 | 38.754
Approved A.C. | | | | Notes Revision Version: 1.0

### REPLACED WITH EXISTING PART THROUGH THE ELECTRONICS STORE

1 pcs: | Total | GBP Price for 1pcs | GBP
38.754

38.75

1/2

# C:\Users\Public\Documents\Altium\Projects\SMAQ-Board_Design\SMAQ-Board_Design.PrjPcb SMAQ-Board_Design.PrjPcb None SMAQ-Board_Design.BomDoc

C:\Users\Public\Documents\Altium\Projects\SMAQ-Board_Design\ActiveBOM\SMAQ-Board_Design.BomDoc

# Bill of Materials Smart Monitoring of Air Quality SMAQ

54
20:02
15/02/2020
28/03/2020 20:02

# Bill of Materials BOM_PartType BOM Bill of Materials

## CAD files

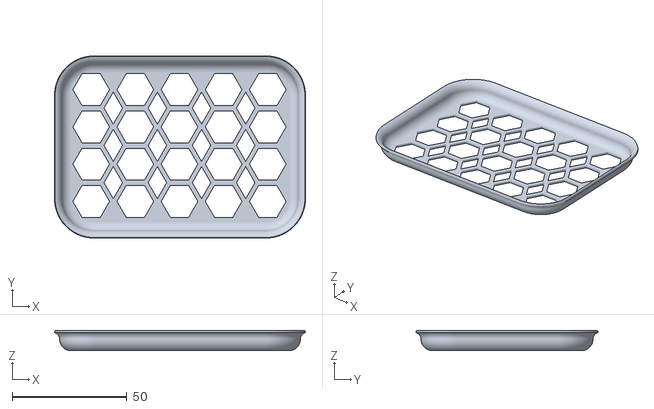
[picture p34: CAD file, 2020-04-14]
Hardware/Casing/Meshed_Panel.stl
109.4 x 79.4 x 8.86

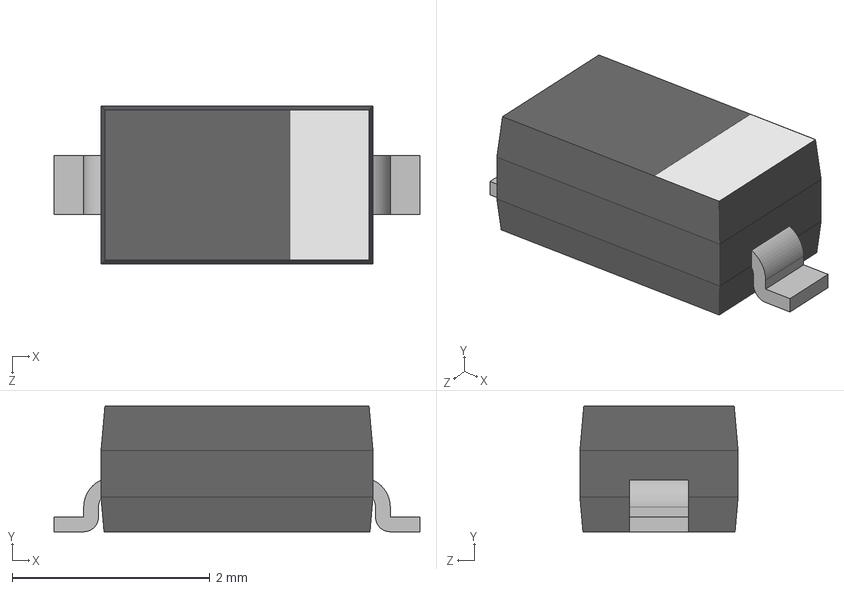
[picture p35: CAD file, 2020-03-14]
Hardware/Source Files/3D Models/CircuitWorks-SOD123.step
3.70 x 1.27 x 1.60 mm

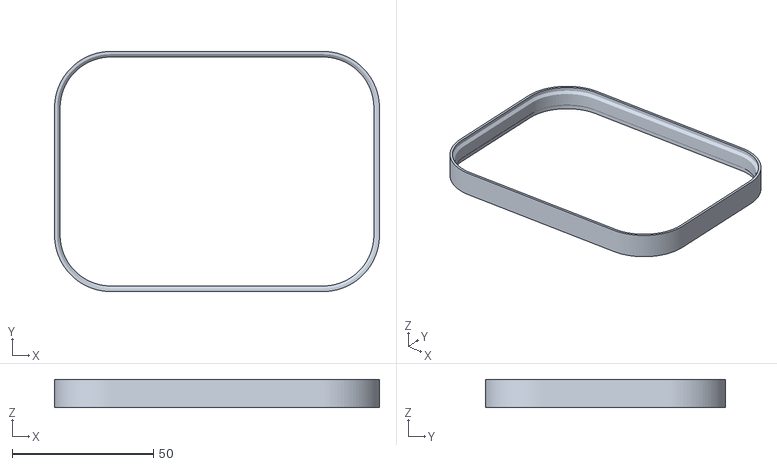
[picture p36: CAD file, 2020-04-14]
Hardware/Casing/LED_Pipe.stl
115.0 x 85.0 x 10.0

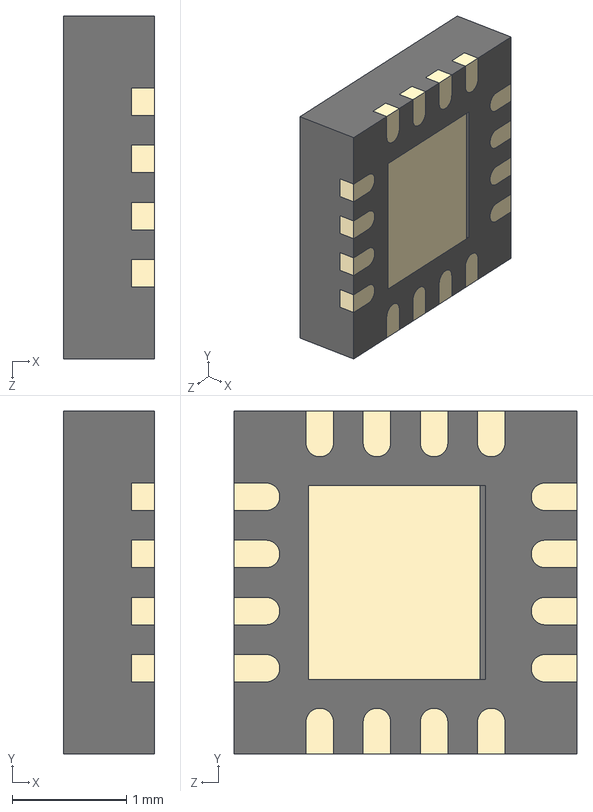
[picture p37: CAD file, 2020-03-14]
Hardware/Source Files/3D Models/TQFN16-1.STEP
0.8 x 3.00 x 3.00 mm

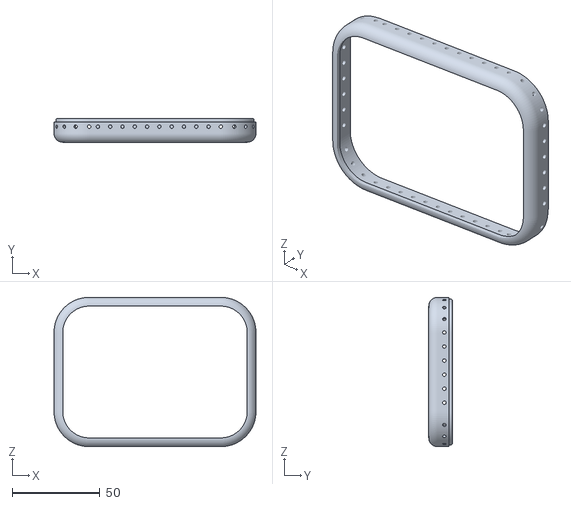
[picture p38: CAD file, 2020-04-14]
Hardware/Casing/Casing_Top_Half.stl
115.0 x 13.4 x 85.0

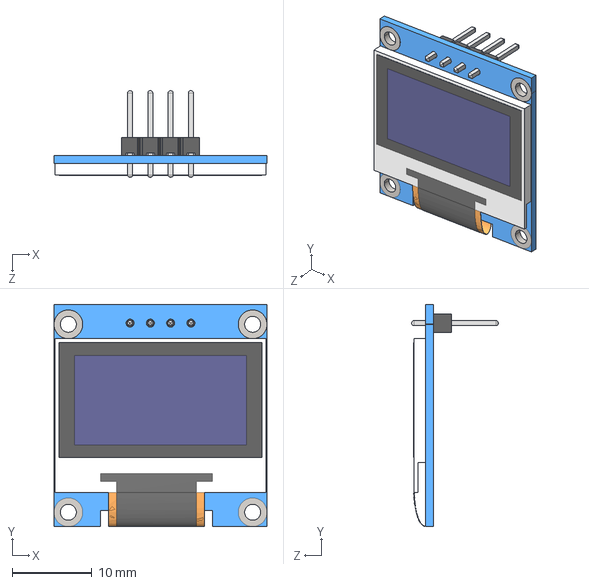
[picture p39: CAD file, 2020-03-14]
Hardware/Source Files/3D Models/User Library-128x64I2COLEDDisplayAdafruit.step
26.7 x 27.9 x 10.8 mm

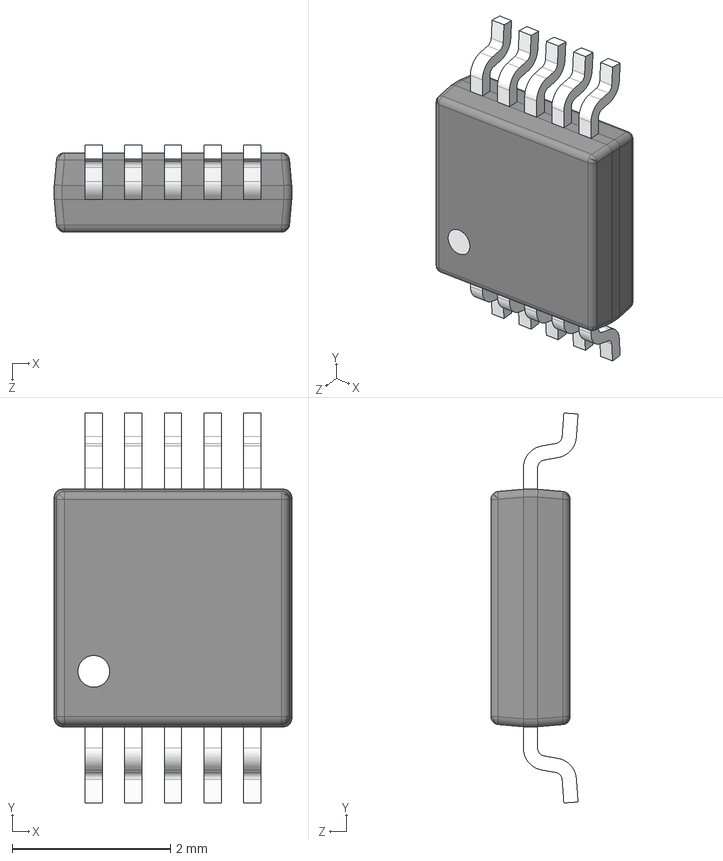
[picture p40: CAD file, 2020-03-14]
Hardware/Source Files/3D Models/User Library-DGS0010A.STEP
3.00 x 4.93 x 1.10 mm
DGS0010A_ASM_LEAD-SO#LEAD-SO;LEAD-SO
DGS0010A_ASM_LEAD-SO#LEAD-SO;LEAD-SO_2
DGS0010A_ASM_LEAD-SO#LEAD-SO;LEAD-SO_3
DGS0010A_ASM_LEAD-SO#LEAD-SO;LEAD-SO_4
DGS0010A_ASM_LEAD-SO#LEAD-SO;LEAD-SO_5
DGS0010A_ASM_LEAD-SO#LEAD-SO;LEAD-SO_6
DGS0010A_ASM_LEAD-SO#LEAD-SO;LEAD-SO_7
DGS0010A_ASM_LEAD-SO#LEAD-SO;LEAD-SO_8
DGS0010A_ASM_LEAD-SO#LEAD-SO;LEAD-SO_9
DGS0010A_ASM_LEAD-SO#LEAD-SO;LEAD-SO_10
DGS0010A_ASM_BODY-SO#BODY-SO;BODY-SO

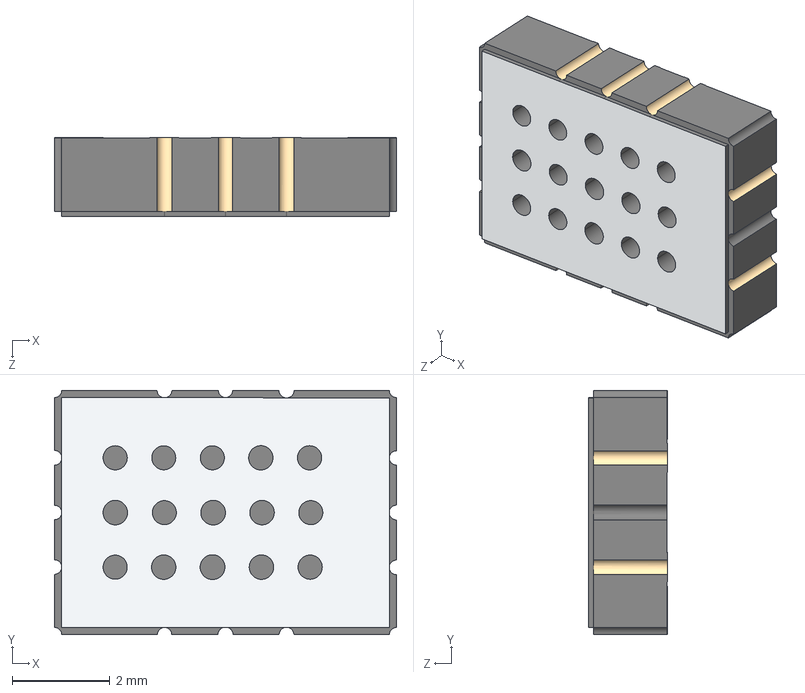
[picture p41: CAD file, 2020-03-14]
Hardware/Source Files/3D Models/User Library-MICS-4514.step
7.00 x 5.00 x 1.61 mm

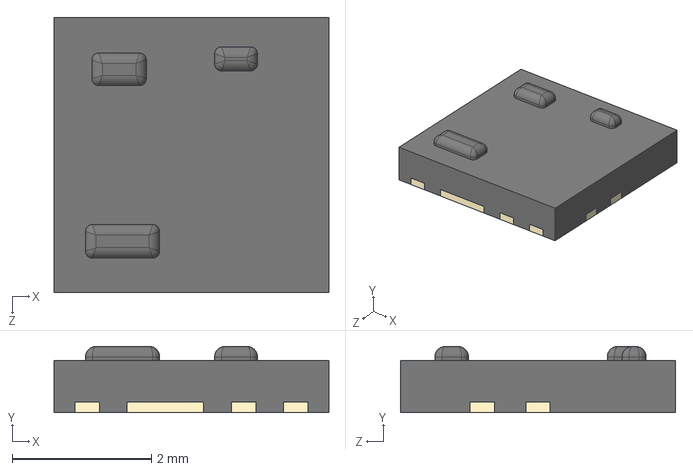
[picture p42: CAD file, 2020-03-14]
Hardware/Source Files/3D Models/VCNL4010.STEP
3.95 x 0.95 x 3.95 mm

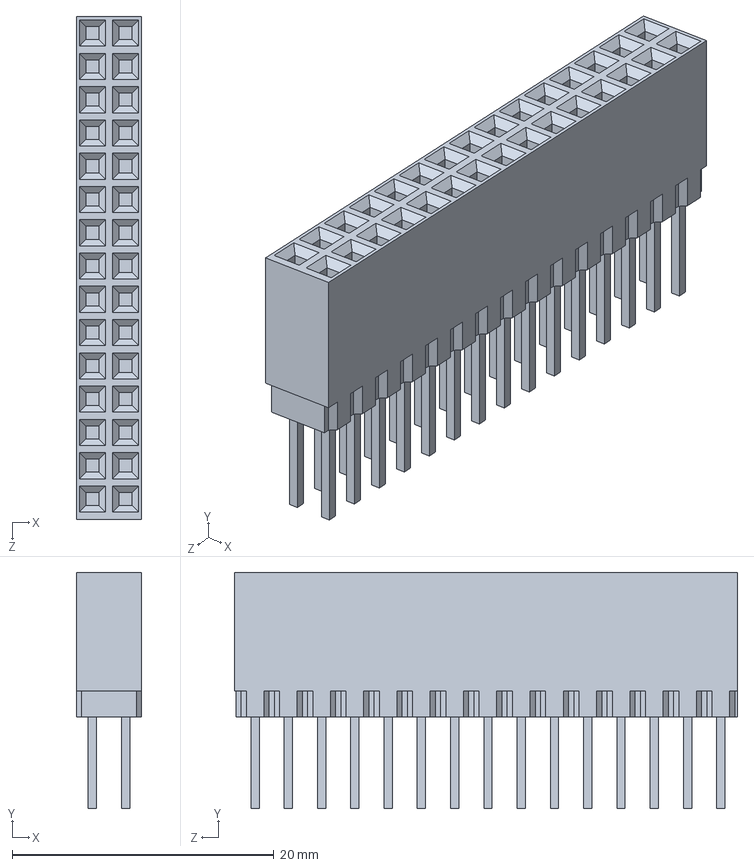
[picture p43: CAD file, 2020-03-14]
Hardware/Source Files/3D Models/30Pin.SLDPRT
5.00 x 18.0 x 38.4 mm

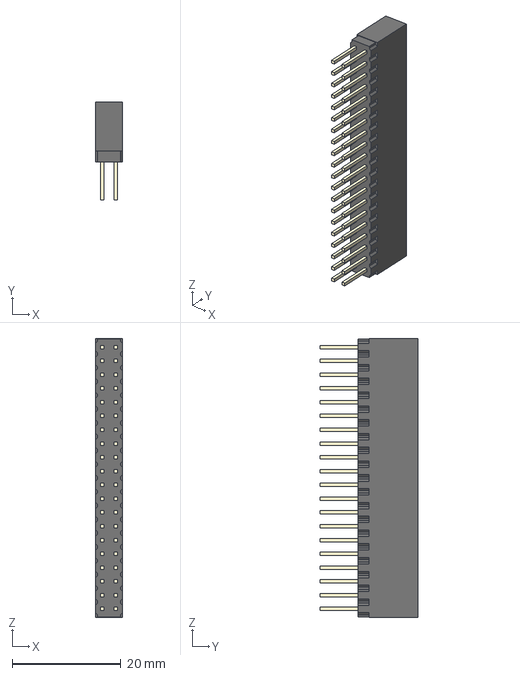
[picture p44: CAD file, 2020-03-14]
Hardware/Source Files/3D Models/40Pin.STEP
5.00 x 18.1 x 51.4 mm

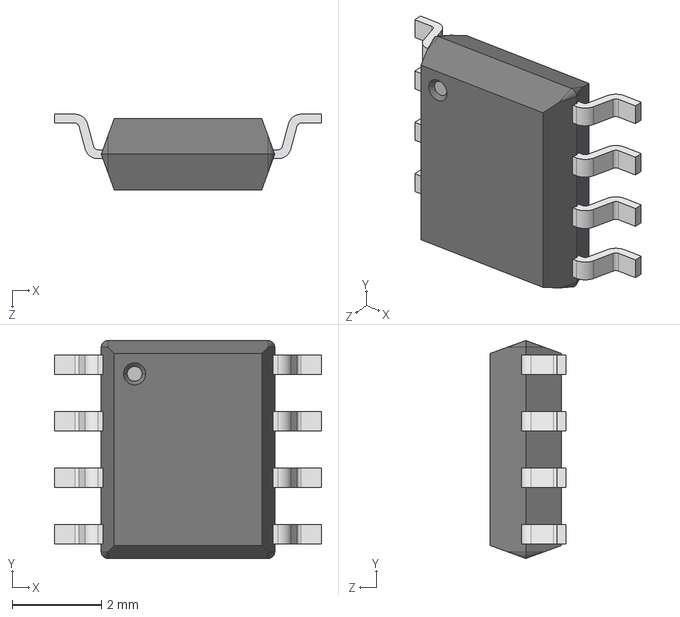
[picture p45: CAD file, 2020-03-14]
Hardware/Source Files/3D Models/User Library-so8-3.step
6.00 x 4.90 x 1.70 mm

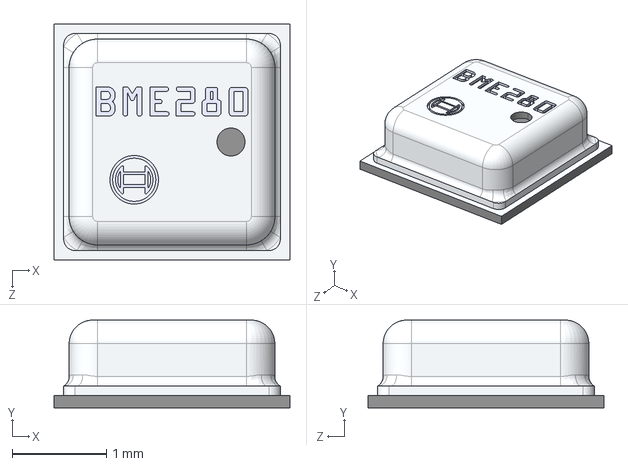
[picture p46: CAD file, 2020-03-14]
Hardware/Source Files/3D Models/User Library-Bosch_BME280.step
2.50 x 0.93 x 2.50 mm

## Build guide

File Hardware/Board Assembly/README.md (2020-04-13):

# Board Assembly Information 

### Here you can find information about:
* [**Draftsman**](https://github.com/MustafaBiyikli/SMAQ/blob/master/Hardware/Board%20Assembly/Draftsman.pdf) **(Refer for complete information for all aspects of the board)**
#### Simplified Drawings
* [Mechanical Drawings](https://github.com/MustafaBiyikli/SMAQ/blob/master/Hardware/Board%20Assembly/Simplified-Mechanical-Drawing.pdf)  (Board dimensions, hole posisitons, general shape information)
* [Top and Bottom Assembly](https://github.com/MustafaBiyikli/SMAQ/blob/master/Hardware/Board%20Assembly/Simplified-Assembly-Drawings.pdf) (Component position with Designators)
* [Top and Bottom View](https://github.com/MustafaBiyikli/SMAQ/blob/master/Hardware/Board%20Assembly/Simplified-TopandBottom-Layers.pdf) (Coloured with appropriate layers)
* [Bill of Materials](https://github.com/MustafaBiyikli/SMAQ/blob/master/Hardware/Board%20Assembly/SMAQ-Board_DesignBOM.pdf) (Ready for Order and as an [Excel File](https://github.com/MustafaBiyikli/SMAQ/blob/master/Hardware/Board%20Assembly/SMAQ-Board_DesignBOM.xlsx))
---

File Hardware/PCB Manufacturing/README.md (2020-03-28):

## Here you can find the appropriate manufacturing files for SMAQ
The gerber output and Drill information can be sent to any PCB Manufacturing service to duplicate the SMAQ. Although an FR-4 is 
recommended for the smallest thickness, the board used in the protoype is an FR-16. 
The layer stackup file indicates the thicknesses and layering on our board.

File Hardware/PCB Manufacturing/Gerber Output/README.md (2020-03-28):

# Gerber Output
*These files can be sent directly to the PCB house*
### Gerber file extensions are:
|Extension| Description|
|---|---|
|GBL| Bottom Silkscreen|
|GBO| Bottom Copper|
|GBS| Bottom Soldermask|
|GTL| Top Copper|
|GTO| Top Silkscreen|
|GTS| Top Soldermask|
|TXT| Drill File|
|dri| Drill Station Info File|
|gpi| Photplotter Info File|
|GML|Mill Layer|
|GTP|Top Paste|

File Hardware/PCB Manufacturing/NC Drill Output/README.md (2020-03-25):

# Drill Output Files
## Drill Size tables
|Symbol|Size|
|---|---|
|x|1.00 mm|
|Square|1.02 mm|
|Triangle|1.10 mm|
|Cross|3.00 mm|

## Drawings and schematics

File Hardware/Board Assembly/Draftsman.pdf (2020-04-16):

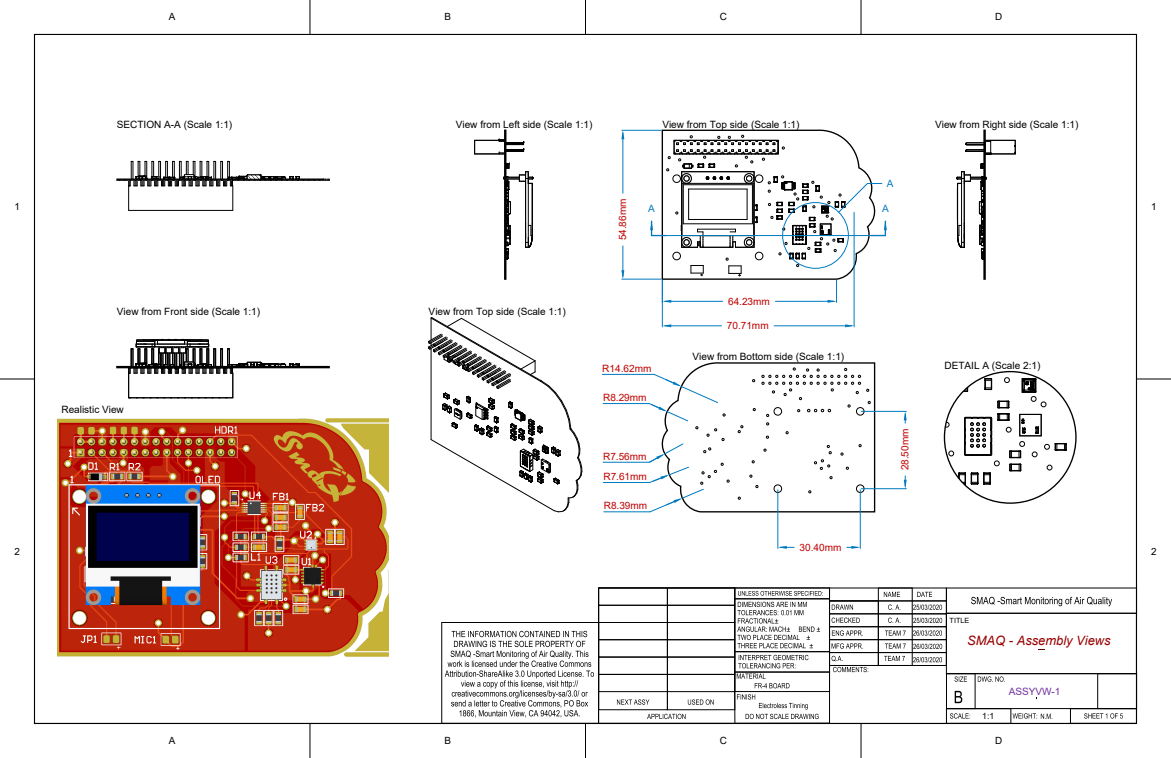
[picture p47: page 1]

View from Top side (Scale 1:1)

View from Front side (Scale 1:1)

View from Bottom side (Scale 1:1)

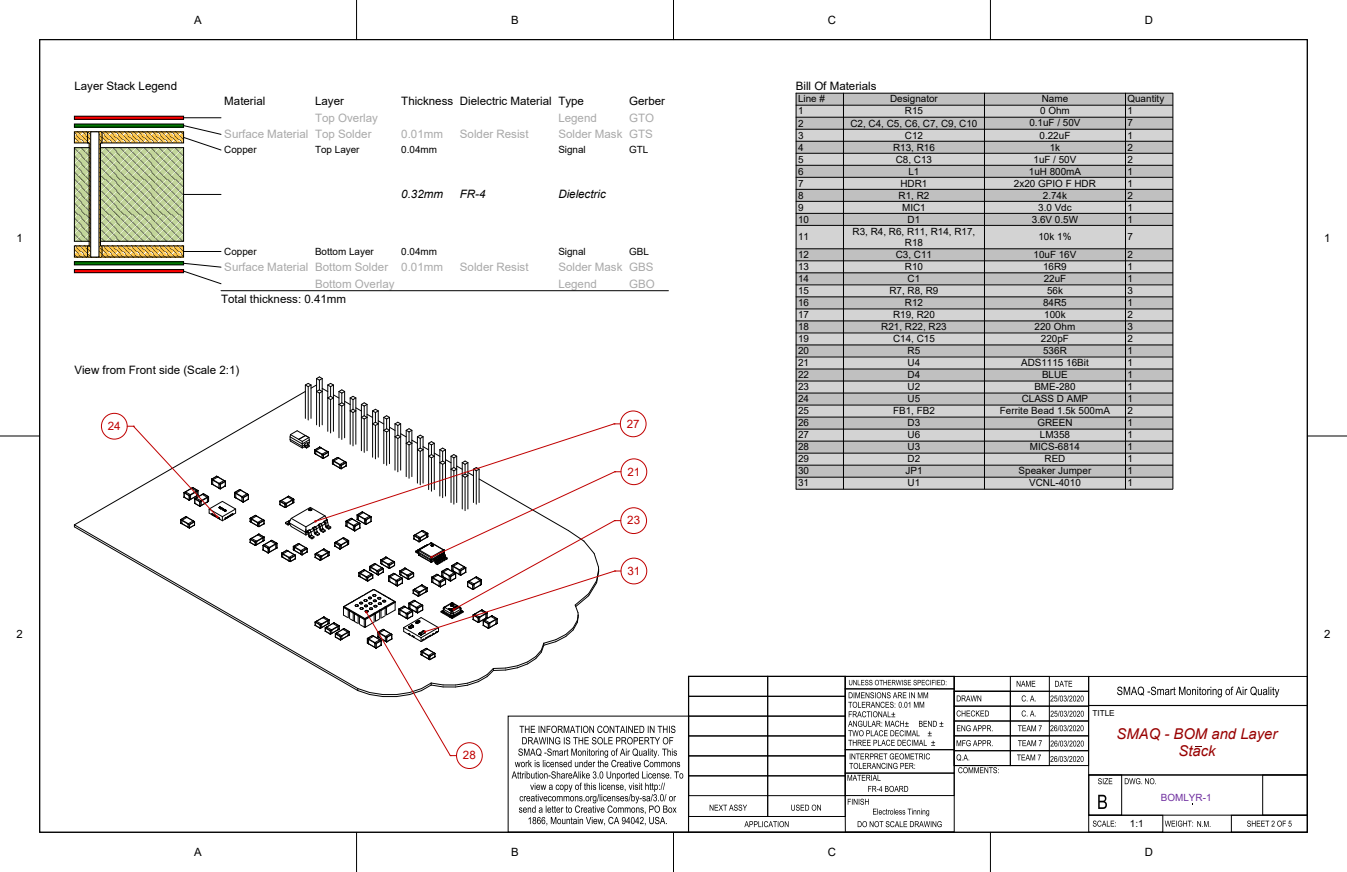
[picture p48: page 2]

View from Front side (Scale 2:1)

TITLE
SMAQ - BOM and Layer

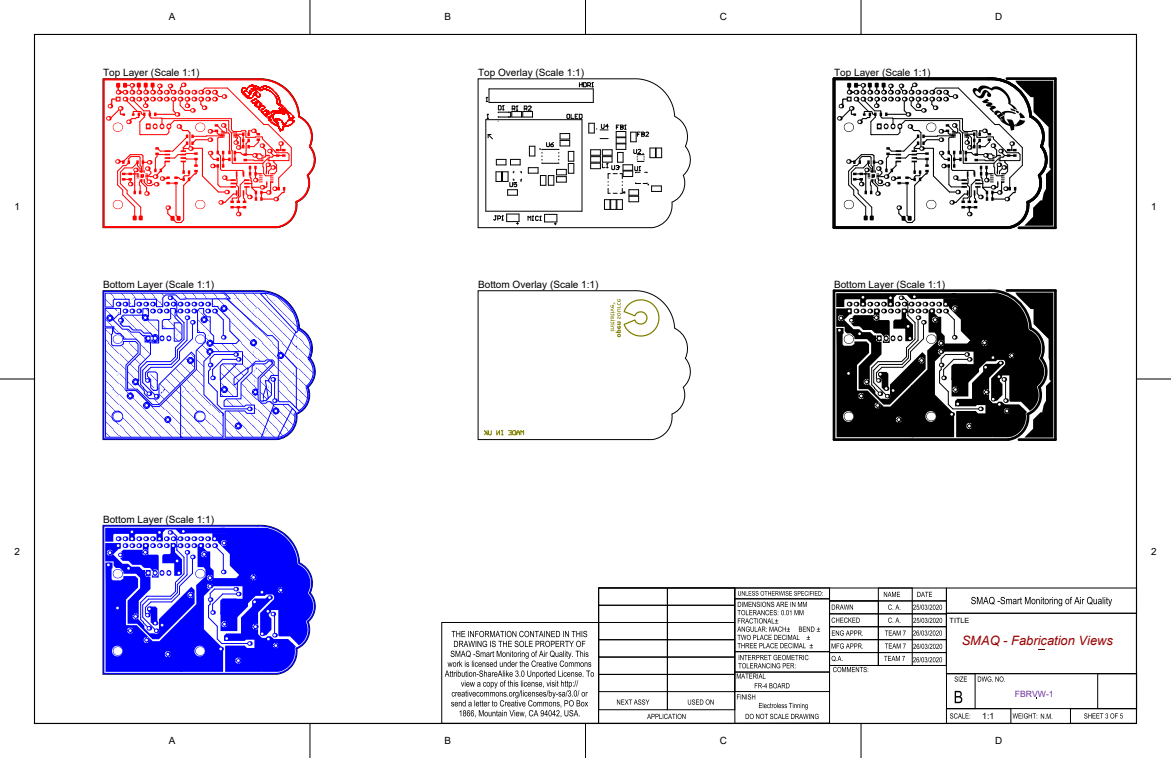
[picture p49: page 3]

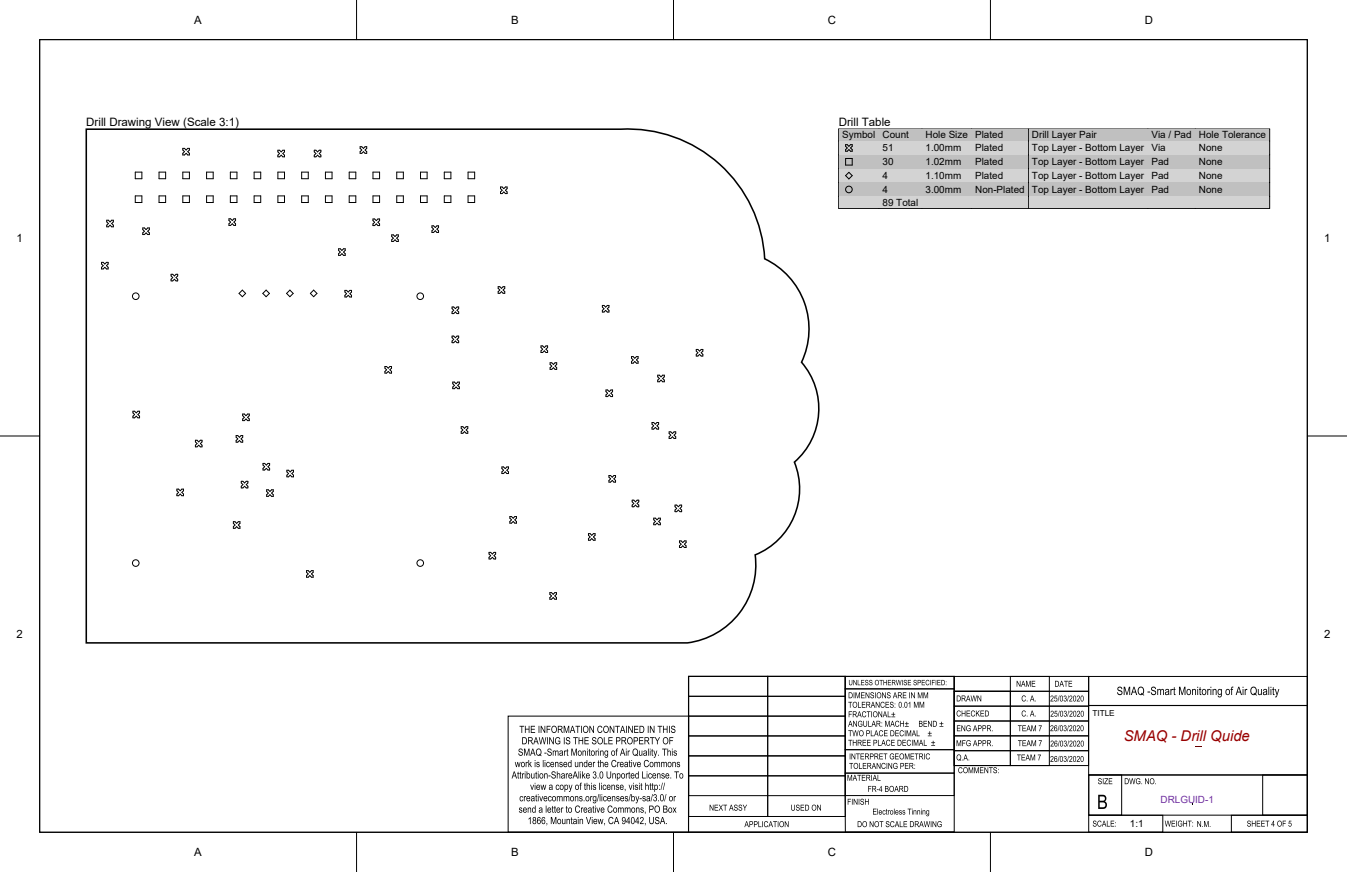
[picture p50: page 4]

Drill Drawing View (Scale 3:1)

Symbol | Count | Hole Size | Plated | Drill Layer Pair | Via / Pad | Hole Tolerance

51 | 1.00mm | Plated | Top Layer - Bottom Layer | Via | None
30 | 1.02mm | Plated | Top Layer - Bottom Layer | Pad | None
4 | 1.10mm | Plated | Top Layer - Bottom Layer | Pad | None
4 | 3.00mm | Non-Plated | Top Layer - Bottom Layer | Pad | None
89 Total

TITLE SMAQ - Drill Quide

DRLGUID-1

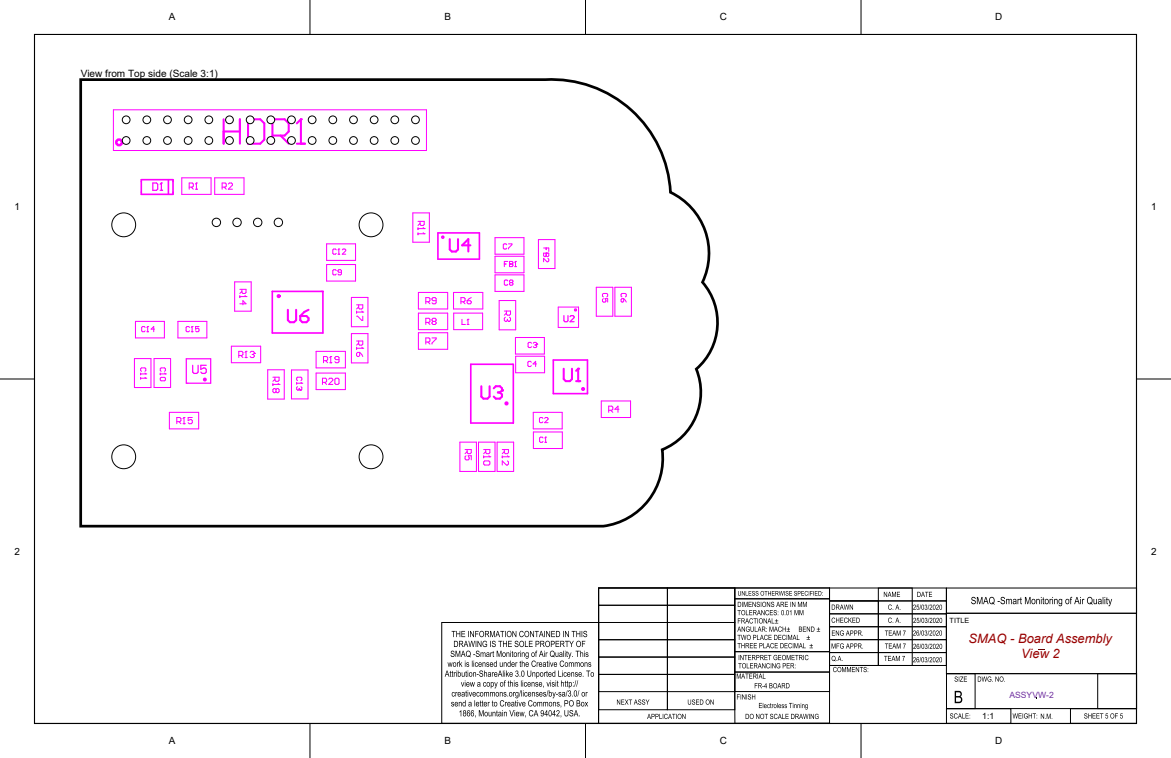
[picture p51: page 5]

View from Top side (Scale 3:1)

TITLE SMAQ - Board Assembly View 2

ASSYVW-2

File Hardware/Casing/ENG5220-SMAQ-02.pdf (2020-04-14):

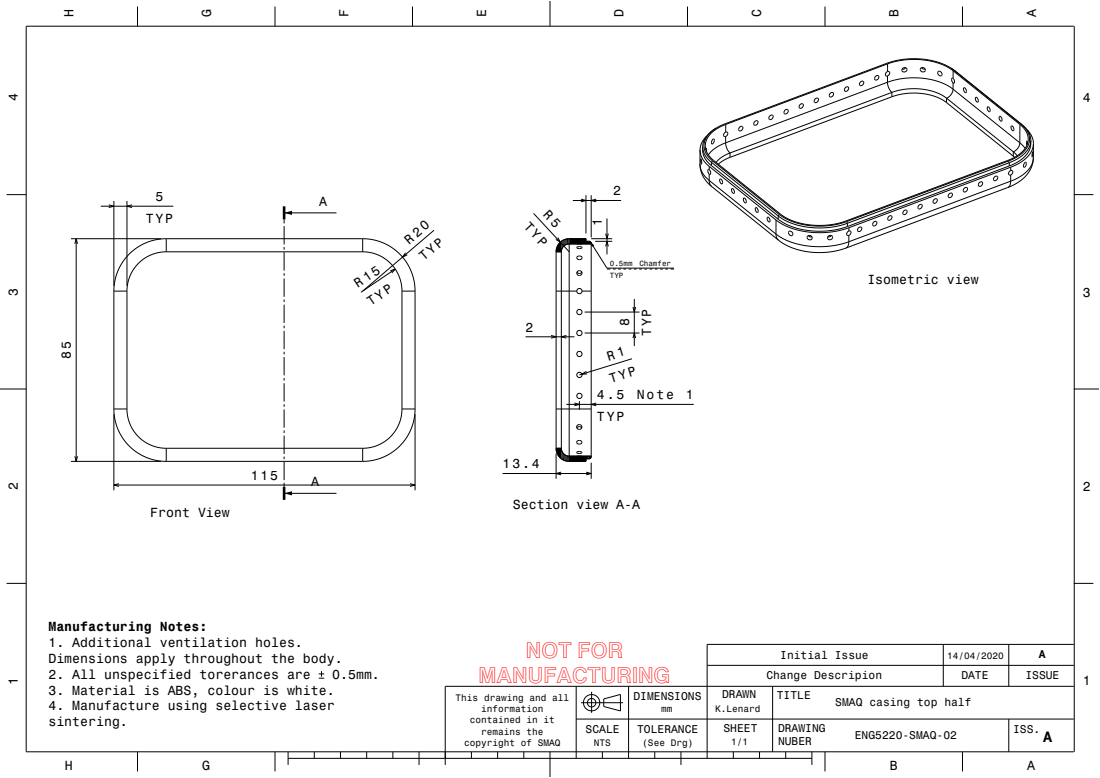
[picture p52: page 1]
NOT FOR; Front View; 2. All unspecified torerances are; 4.5 Note 1; Section view A-A; Isometric view

Manufacturing Notes:
1. Additional ventilation holes.
Dimensions apply throughout the body.
3. Material is ABS, colour is white.
4. Manufacture using selective laser
sintering.

Initial Issue | 14/04/2020 | A
Change Descripion | DATE | ISSUE

This drawing and all information contained in it remains the copyright of SMAQ | | | | | DIMENSIONS mm | DRAWN K.Lenard | TITLE SMAQ casing top half

SCALE NTS | TOLERANCE (See Drg) | SHEET 1/1 | DRAWING ENG5220-SMAQ-02 NUBER | ISS. A

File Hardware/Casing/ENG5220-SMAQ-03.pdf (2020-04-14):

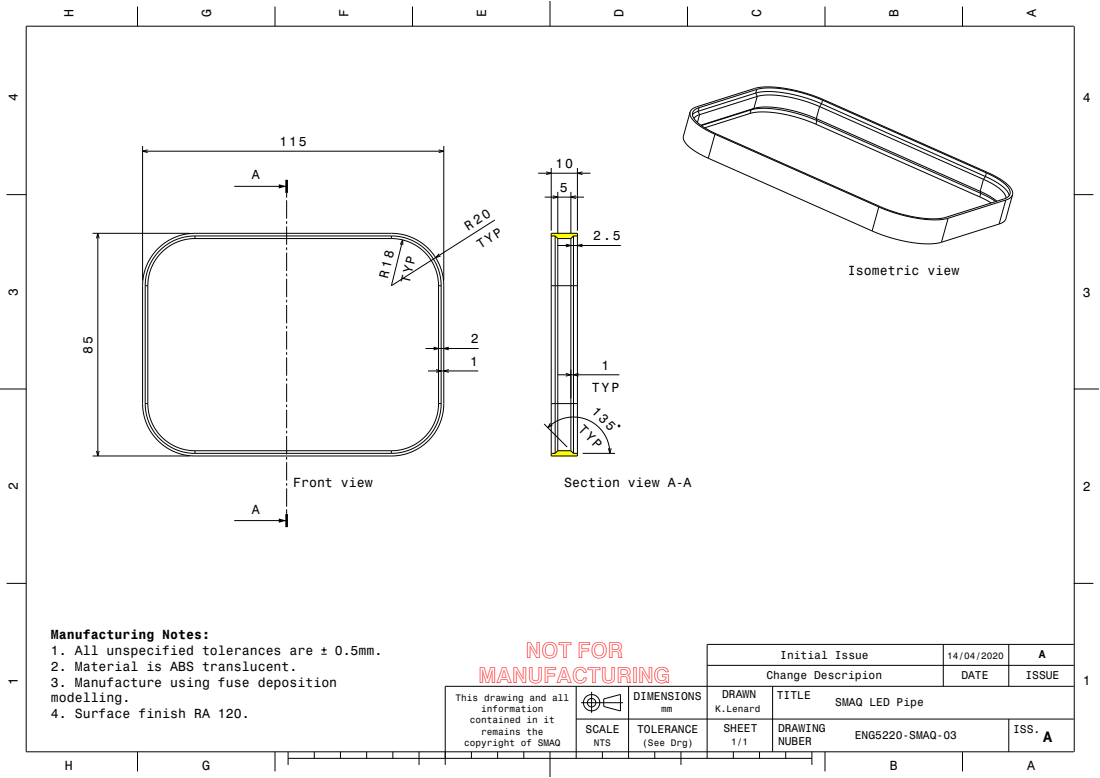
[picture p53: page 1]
NOT FOR; Front view; 1. All unspecified tolerances are; Section view A-A; Isometric view

Manufacturing Notes:
2. Material is ABS translucent.
3. Manufacture using fuse deposition
modelling.
4. Surface finish RA 120.

Initial Issue | 14/04/2020 | A
Change Descripion | DATE | ISSUE

This drawing and all information contained in it remains the copyright of SMAQ | | | | | DIMENSIONS mm | DRAWN K.Lenard | TITLE SMAQ LED Pipe

SCALE NTS | TOLERANCE (See Drg) | SHEET 1/1 | DRAWING ENG5220-SMAQ-03 NUBER | ISS. A

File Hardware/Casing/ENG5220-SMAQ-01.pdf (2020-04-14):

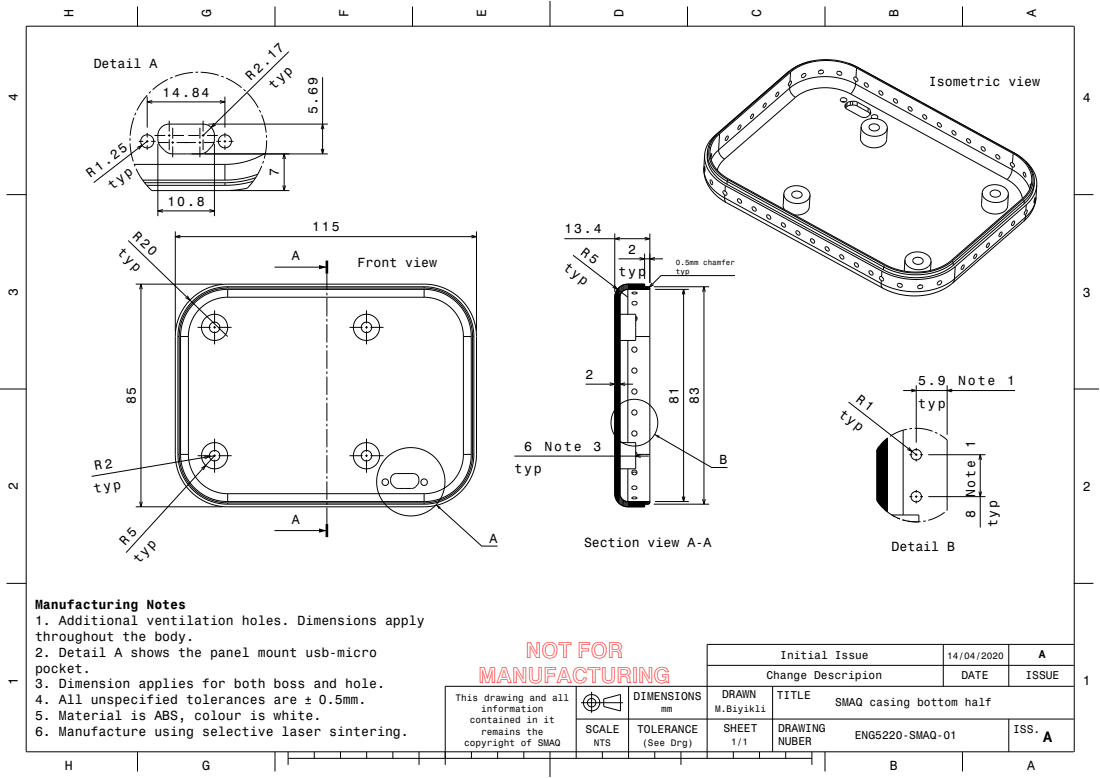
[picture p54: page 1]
NOT FOR; Front view; 4. All unspecified tolerances are; Section view A-A; 0.5mm chamfer; 6 Note 3; Detail B; 8 Note 1; 5.9 Note 1; Detail A; Isometric view

Manufacturing Notes
1. Additional ventilation holes. Dimensions apply
throughout the body.
2. Detail A shows the panel mount usb-micro
pocket.
3. Dimension applies for both boss and hole.
5. Material is ABS, colour is white.
6. Manufacture using selective laser sintering.

Initial Issue | 14/04/2020 | A
Change Descripion | DATE | ISSUE

This drawing and all information contained in it remains the copyright of SMAQ | | | | | DIMENSIONS mm | DRAWN M.Biyikli | TITLE SMAQ casing bottom half

SCALE NTS | TOLERANCE (See Drg) | SHEET 1/1 | DRAWING ENG5220-SMAQ-01 NUBER | ISS. A

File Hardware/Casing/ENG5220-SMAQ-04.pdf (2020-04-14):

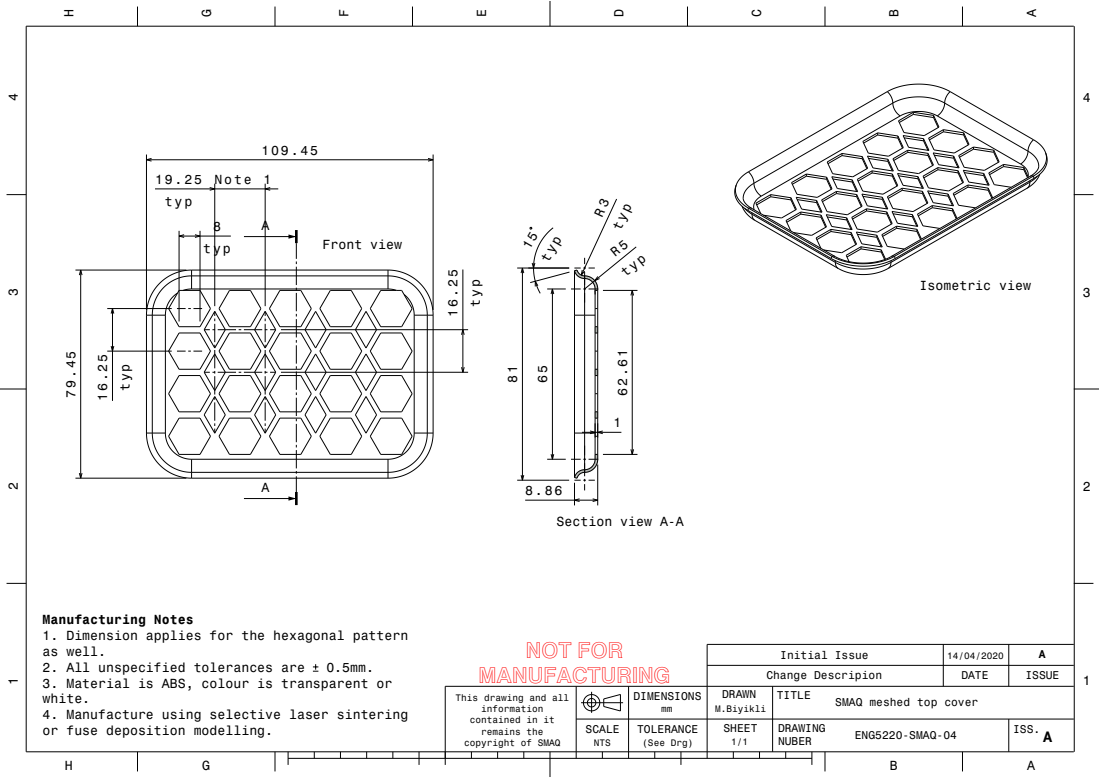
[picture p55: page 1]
NOT FOR; Front view; 19.25 Note 1; 2. All unspecified tolerances are; Section view A-A 62.61; Isometric view

Manufacturing Notes
1. Dimension applies for the hexagonal pattern
as well.
3. Material is ABS, colour is transparent or
white.
4. Manufacture using selective laser sintering
or fuse deposition modelling.

Initial Issue | 14/04/2020 | A
Change Descripion | DATE | ISSUE

This drawing and all information contained in it remains the copyright of SMAQ | | | | | DIMENSIONS mm | DRAWN M.Biyikli | TITLE SMAQ meshed top cover

SCALE NTS | TOLERANCE (See Drg) | SHEET 1/1 | DRAWING ENG5220-SMAQ-04 NUBER | ISS. A

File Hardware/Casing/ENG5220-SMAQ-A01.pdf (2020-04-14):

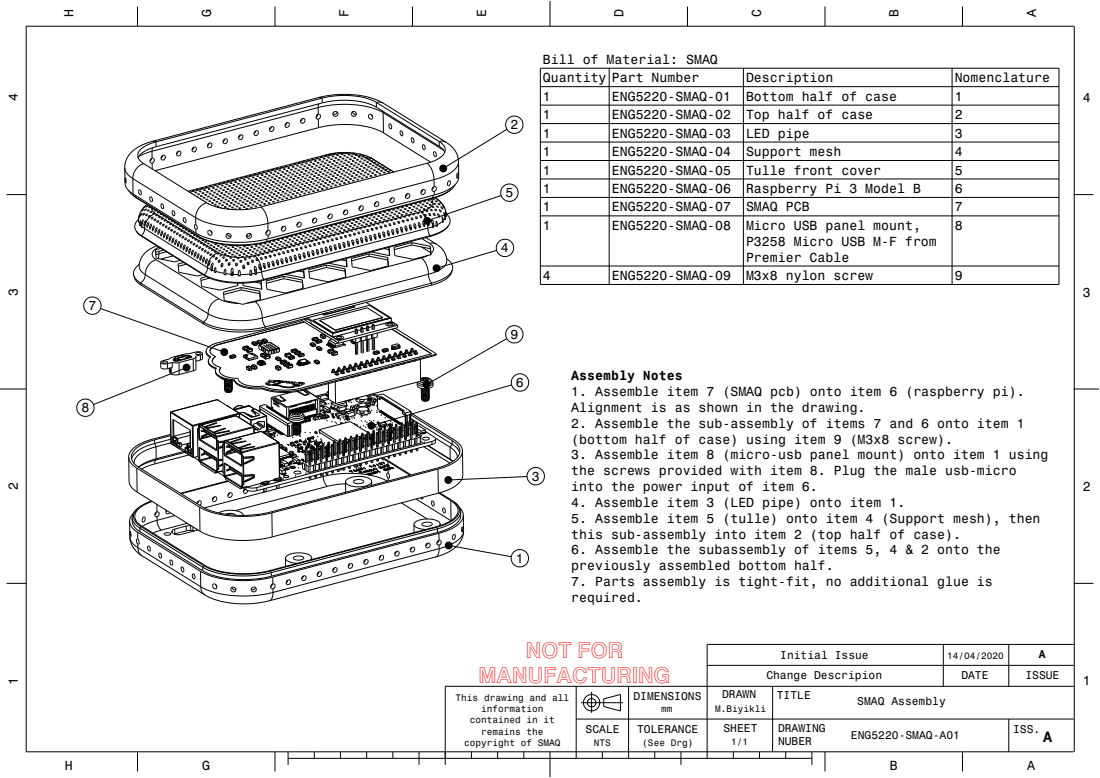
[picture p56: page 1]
Initial Issue; Change Descripion; NTS; (See Drg); SMAQ Assembly; Quantity Part Number; Description; Nomenclature 1; ENG5220-SMAQ-01 Bottom half of case; ENG5220-SMAQ-02 Top half of case; ENG5220-SMAQ-03 LED pipe; ENG5220-SMAQ-04 Support mesh; ENG5220-SMAQ-05 Tulle front cover; ENG5220-SMAQ-06 Raspberry Pi 3 Model B; ENG5220-SMAQ-07 SMAQ PCB; ENG5220-SMAQ-08 Micro USB panel mount,; ENG5220-SMAQ-09 M3x8 nylon screw

Bill of Material: SMAQ

P3258 Micro USB M-F from
Premier Cable

Assembly Notes
1. Assemble item 7 (SMAQ pcb) onto item 6 (raspberry pi).
Alignment is as shown in the drawing.
2. Assemble the sub-assembly of items 7 and 6 onto item 1
(bottom half of case) using item 9 (M3x8 screw).
3. Assemble item 8 (micro-usb panel mount) onto item 1 using
the screws provided with item 8. Plug the male usb-micro
into the power input of item 6.
4. Assemble item 3 (LED pipe) onto item 1.
5. Assemble item 5 (tulle) onto item 4 (Support mesh), then
this sub-assembly into item 2 (top half of case).
6. Assemble the subassembly of items 5, 4 & 2 onto the
previously assembled bottom half.
7. Parts assembly is tight-fit, no additional glue is
required.
NOT FOR
MANUFACTURING

This drawing and all
information
contained in it
remains the
copyright of SMAQ

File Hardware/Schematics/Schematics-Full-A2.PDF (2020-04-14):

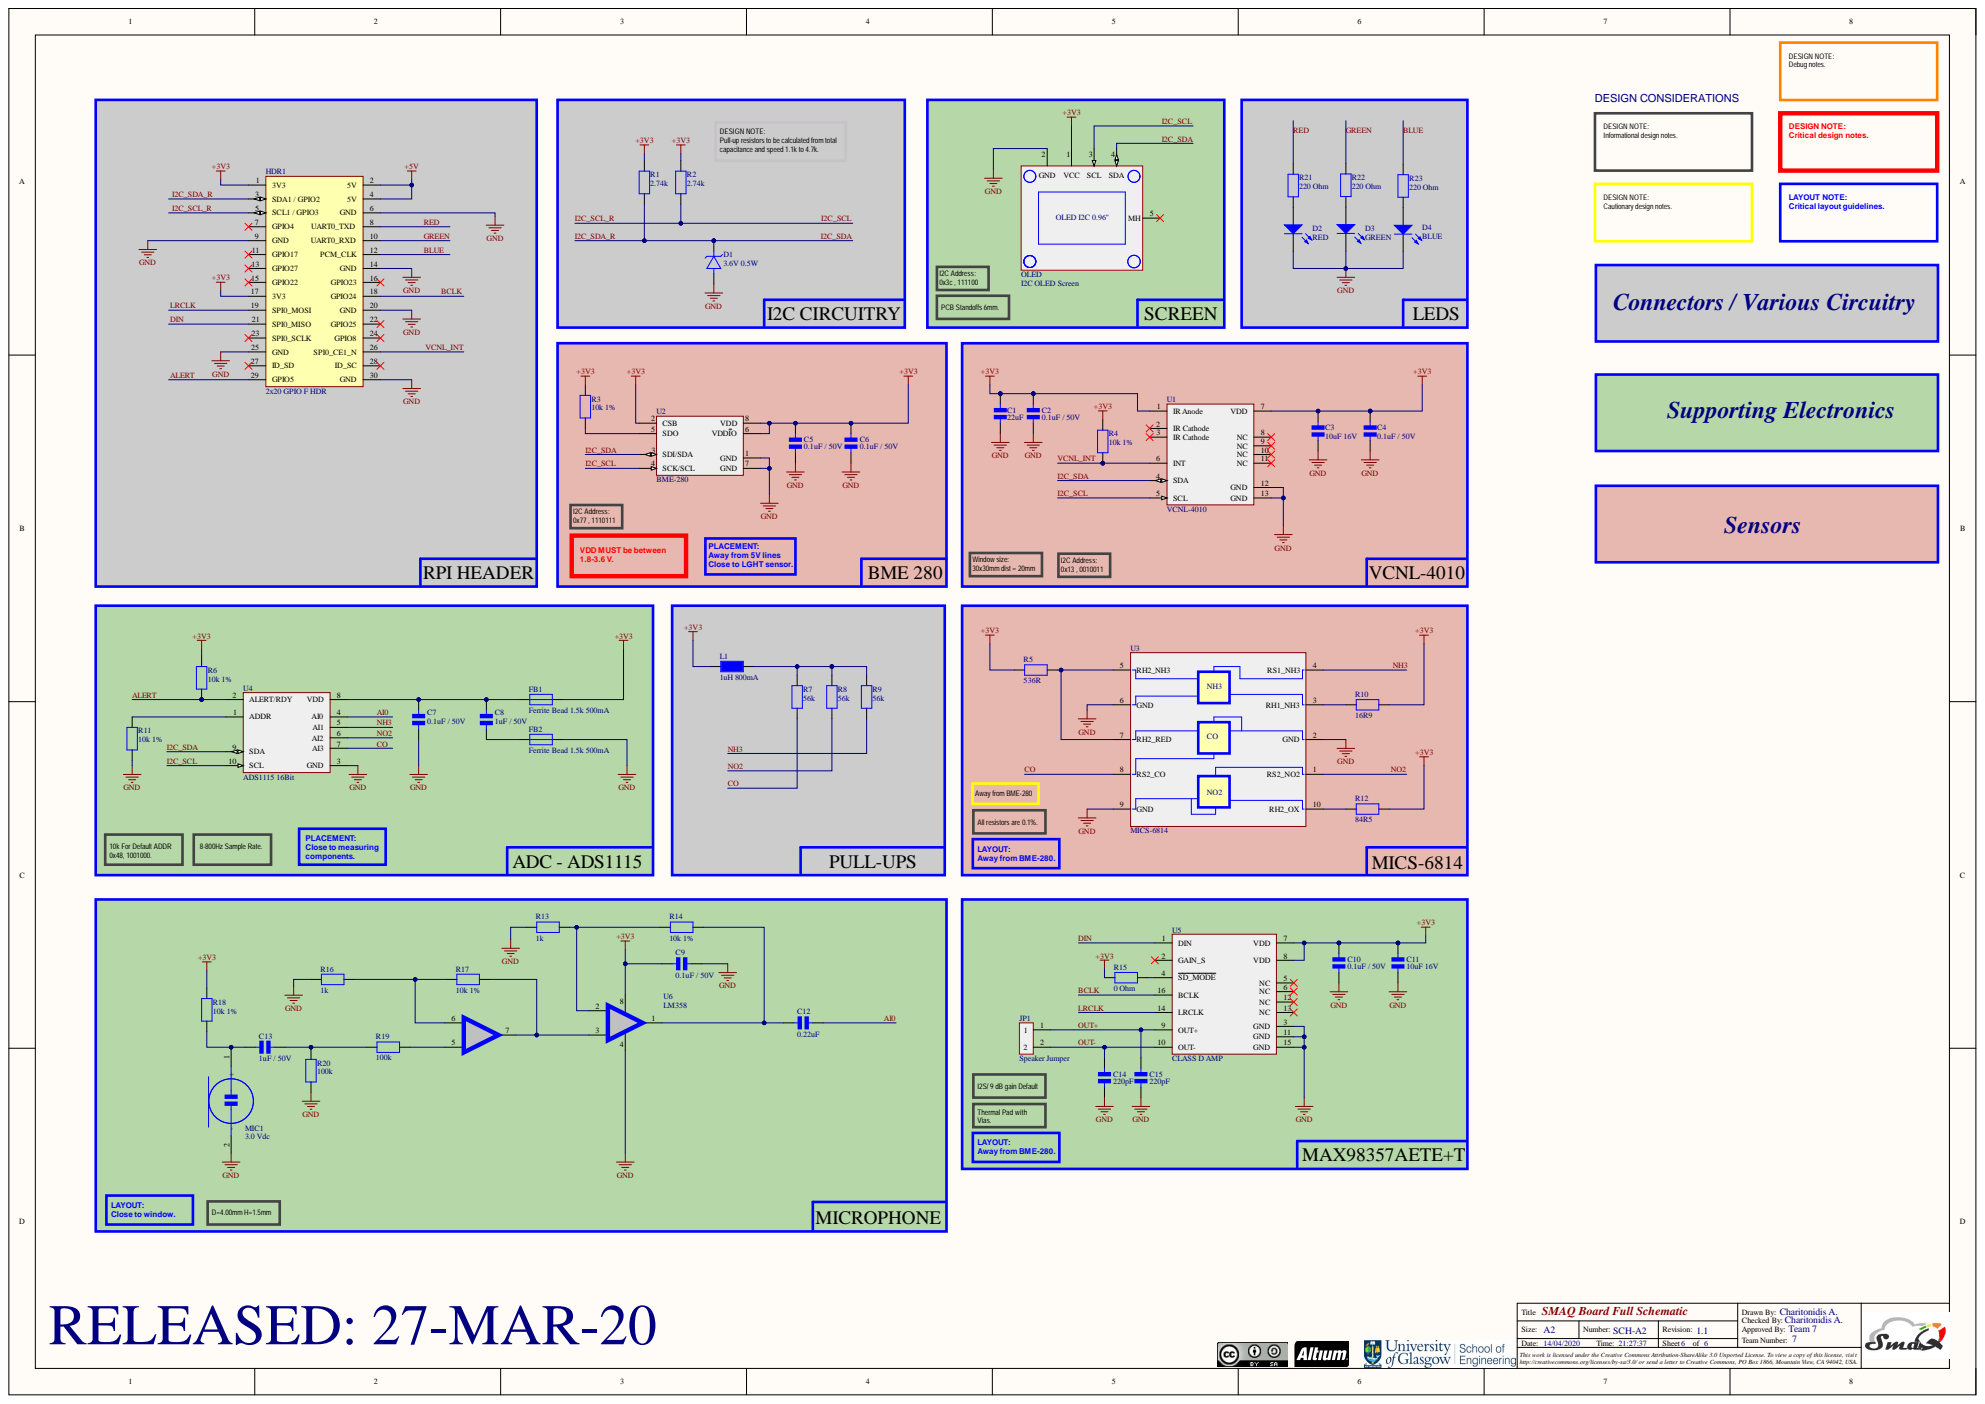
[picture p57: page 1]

DESIGN NOTE:
Pull-up resistors to be calculated from total
capacitance and speed 1.1k to 4.7k.

VDD MUST be between

PLACEMENT:
Away from 5V lines
Close to LGHT sensor.

SMAQ Board Full Schematic
Title

Drawn By: Charitonidis A. Checked By: Charitonidis A. Approved By: Team 7

Size: A2 | Number: SCH-A2 | Revision: 1.1

Date: 14/04/2020 Time: 21:27:37 | | Sheet 6 of 6

This work is licensed under the Creative Commons Attribution-ShareAlike 3.0 Unported License. To view a copy of this license, visit
http://creativecommons.org/licenses/by-sa/3.0/ or send a letter to Creative Commons, PO Box 1866, Mountain View, CA 94042, USA.

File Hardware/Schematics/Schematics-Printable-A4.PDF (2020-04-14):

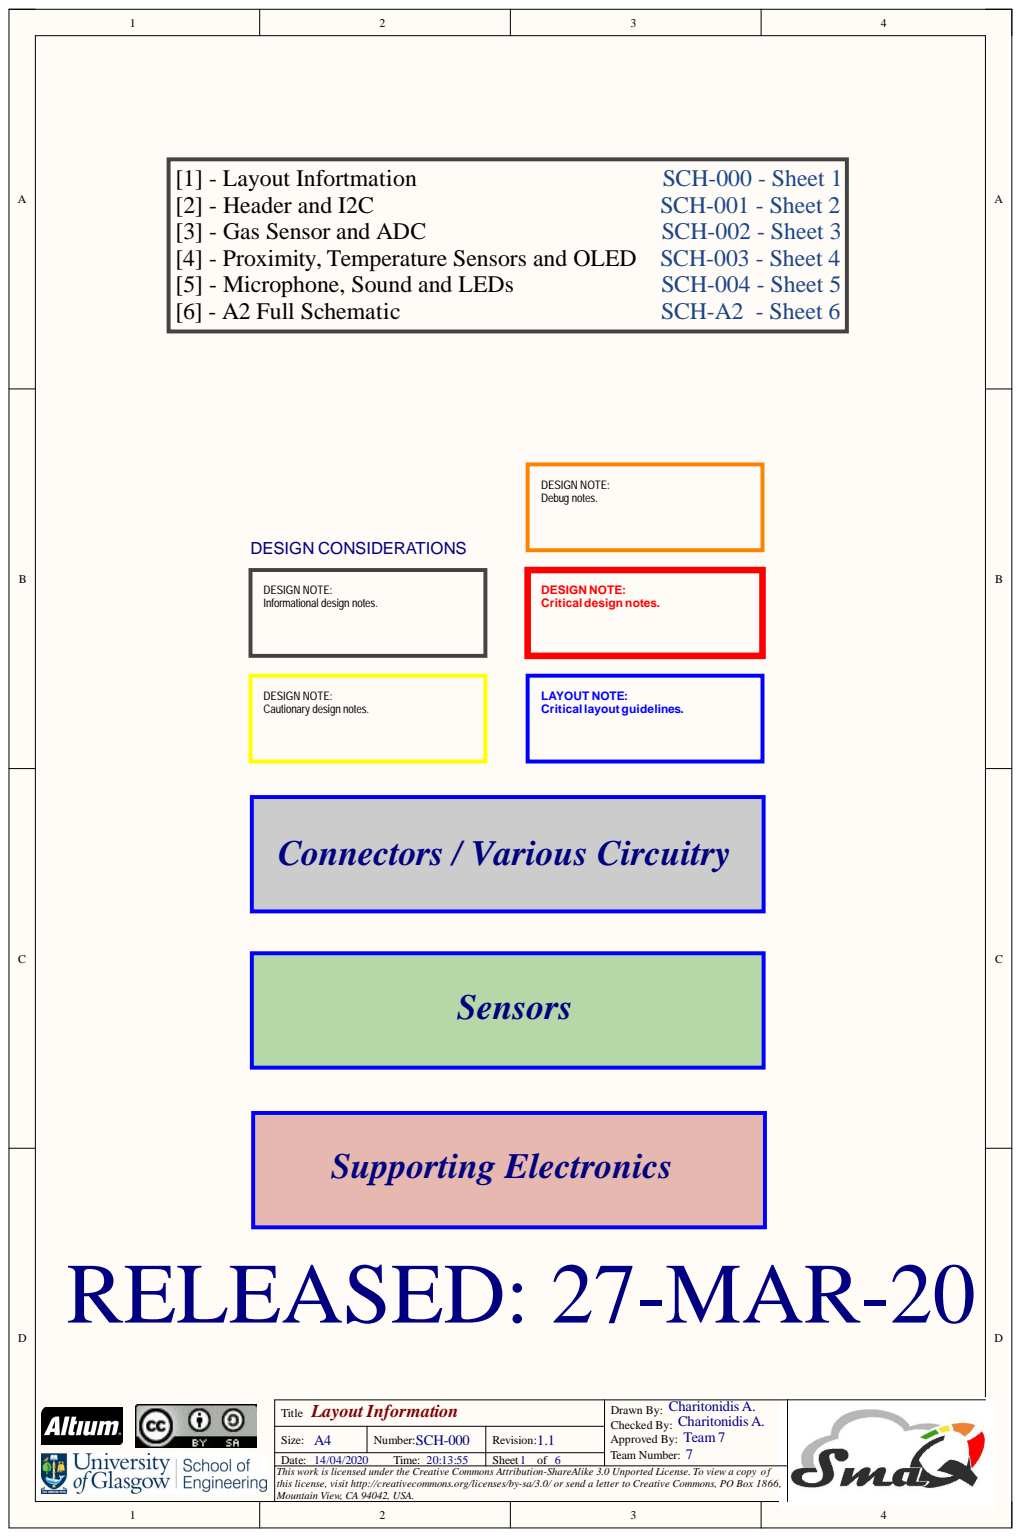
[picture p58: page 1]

[1] - Layout Infortmation
[2] - Header and I2C
[3] - Gas Sensor and ADC
[4] - Proximity, Temperature Sensors and OLED
[5] - Microphone, Sound and LEDs
[6] - A2 Full Schematic

Size: A4 | Number: SCH-000 | Revision: 1.1
Date: 14/04/2020 Time: 20:13:55 | | Sheet of

This work is licensed under the Creative Commons Attribution-ShareAlike 3.0 Unported License. To view a copy of
this license, visit http://creativecommons.org/licenses/by-sa/3.0/ or send a letter to Creative Commons, PO Box 1866,
Mountain View, CA 94042, USA.


DESIGN NOTE:
Pull-up resistors to be calculated from total
capacitance and speed 1.1k to 4.7k.


Gas Sensor and ADC


VDD MUST be between

PLACEMENT:
Away from 5V lines
Close to LGHT sensor.

Proximity,Temperature Sensors+OLED


Microphone,Sound and LEDs







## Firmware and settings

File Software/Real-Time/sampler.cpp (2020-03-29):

#include <iostream>
#include <thread>
#include <ostream>
#include <ctime>

#include "sampler.h"
#include "VCNL4010.h"
#include "BME280.h"
#include "ADS1115.h"
#include "SH1106.h"
#include "wiringPiI2C.h"

using namespace std;

BME280 *bme280 = new BME280();
VCNL4010 *vcnl4010 = new VCNL4010();
ADS1115 *ads1115 = new ADS1115();
SH1106 *sh1106 = new SH1106();

Communicate::Communicate()
{
    fd_VCNL4010 = wiringPiI2CSetup(VCNL4010_ADDRESS);
    if (fd_VCNL4010 < 0)
        throw "I2C communication failed";

    fd_BME280 = wiringPiI2CSetup(BME280_ADDRESS);
    if (fd_BME280 < 0)
        throw "I2C communication failed";

    fd_ADS1115 = wiringPiI2CSetup(ADS1115_ADDRESS);
    if (fd_ADS1115 < 0)
        throw "I2C communication failed";

    fd_SH1106 = wiringPiI2CSetup(SH1106_ADDRESS);
    if (fd_SH1106 < 0)
        throw "I2C communication failed";
}

void Communicate::setCallBack(Callback *cb)
{
    callback = cb;
}

void Communicate::run(Communicate *communicate)
{
    communicate->running = 1;

    while (communicate->running)
    {
        communicate->interruptStatus = wiringPiI2CReadReg8(communicate->fd_VCNL4010, VCNL4010_COMMAND);
        if (communicate->interruptStatus & VCNL4010_AMBIENTREADY)
        {
            // timeStamp
            time_t timeStamp = time(0);

            // VCNL4010
            float ambientLight = vcnl4010->getAmbient(communicate->fd_VCNL4010);
            float proximity = vcnl4010->getProximity(communicate->fd_VCNL4010);

            // BME280
            float temperature = bme280->extractData(communicate->fd_BME280, bme280->TEMPERATURE);
            float pressure = bme280->extractData(communicate->fd_BME280, bme280->PRESSURE);
            float humidity = bme280->extractData(communicate->fd_BME280, bme280->HUMIDITY);
            float altitude = bme280->extractData(communicate->fd_BME280, bme280->ALTITUDE);

            // ADS1115
            float microphone = ads1115->get_ADS1115_Converted(communicate->fd_ADS1115, ads1115->MICROPHONE);
            float nh3 = ads1115->get_ADS1115_Converted(communicate->fd_ADS1115, ads1115->NH3);
            float no2 = ads1115->get_ADS1115_Converted(communicate->fd_ADS1115, ads1115->NO2);
            float co = ads1115->get_ADS1115_Converted(communicate->fd_ADS1115, ads1115->CO);

            // STORE RESULTS
            communicate->callback->hasSample(timeStamp, ambientLight, proximity, temperature, pressure, humidity, altitude,
                                             microphone, nh3, no2, co);
        }
    }
}

void Communicate::start(int samplingRate)
/** sampling-rates: _1HZ, _2HZ, _3HZ, _4HZ, _5HZ, _6HZ, _8HZ, _10HZ **/
{
    if (Thread)
        throw "Called while sensor is already running";
    if (samplingRate < 0 || samplingRate > 7)
        throw "Invalid sampling rate";

    // VCNL4010 configure + Set interrupt
    vcnl4010->VCNL4010config(fd_VCNL4010, samplingRate);

    // BME280 congfigure
    bme280->BME280config(fd_BME280, samplingRate);

    // ADS1115 configure
    ads1115->ADS1115config(fd_ADS1115, samplingRate);

    // SH1106 configure and display SMAQ logo
    sh1106->sh1106_init(fd_SH1106);
    sh1106->sh1106_display(fd_SH1106);

    Thread = new thread(run, this);
}

void Communicate::stop()
{
    running = 0;
    sh1106->sh1106_displayOFF(fd_SH1106);

    if (Thread)
    {
        Thread->join();
        delete Thread;
        Thread = NULL;
    }
}

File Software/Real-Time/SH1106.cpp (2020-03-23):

#include <iostream>
#include <cerrno>
#include <cstdint>
#include <ctime>
#include <cstring>
#include <string>
#include <sstream>
#include <iterator>
#include <vector>
#include <stdexcept>
#include <ostream>
#include <cmath>

#include "fonts.h"
#include "SH1106.h"
#include "wiringPiI2C.h"

using namespace std;

int cursor_x = 0;
int cursor_y = 0;
int textsize = 1;
int wrap = 1;

#define pgm_read_byte(addr) (*(const unsigned char *)(addr))

#define sh1106_swap(a, b) \
    {                     \
        int t = a;        \
        a = b;            \
        b = t;            \
    }

void SH1106::sh1106_init(int fd_SH1106)
{
    wiringPiI2CWriteReg8(fd_SH1106, control, SH1106_DISPLAYOFF);
    wiringPiI2CWriteReg8(fd_SH1106, control, SH1106_SETDISPLAYCLOCKDIV);
    wiringPiI2CWriteReg8(fd_SH1106, control, 0xF0); // Suggested Ratio
    wiringPiI2CWriteReg8(fd_SH1106, control, SH1106_SETMULTIPLEX);
    wiringPiI2CWriteReg8(fd_SH1106, control, 0x3f);
    wiringPiI2CWriteReg8(fd_SH1106, control, SH1106_SETDISPLAYOFFSET);
    wiringPiI2CWriteReg8(fd_SH1106, control, 0x00);                      // No Offest
    wiringPiI2CWriteReg8(fd_SH1106, control, SH1106_SETSTARTLINE | 0x0); // Line 0
    wiringPiI2CWriteReg8(fd_SH1106, control, SH1106_CHARGEPUMP);
    wiringPiI2CWriteReg8(fd_SH1106, control, 0x10); // internal VCC: 0x14 | external VCC: 0x10
    wiringPiI2CWriteReg8(fd_SH1106, control, SH1106_MEMORYMODE);
    wiringPiI2CWriteReg8(fd_SH1106, control, 0x00);
    wiringPiI2CWriteReg8(fd_SH1106, control, 0xB0); // page 0
    wiringPiI2CWriteReg8(fd_SH1106, control, SH1106_COMSCANDEC);
    wiringPiI2CWriteReg8(fd_SH1106, control, SH1106_SETLOWCOLUMN);
    wiringPiI2CWriteReg8(fd_SH1106, control, SH1106_SETHIGHCOLUMN);

    wiringPiI2CWriteReg8(fd_SH1106, control, SH1106_SETCOMPINS);
    wiringPiI2CWriteReg8(fd_SH1106, control, 0x12);
    wiringPiI2CWriteReg8(fd_SH1106, control, SH1106_SETCONTRAST);
    wiringPiI2CWriteReg8(fd_SH1106, control, 0x9F); // internal VCC: 0xCF | external VCC: 0x9F

    wiringPiI2CWriteReg8(fd_SH1106, control, SH1106_SEGREMAP);
    wiringPiI2CWriteReg8(fd_SH1106, control, SH1106_SETPRECHARGE);
    wiringPiI2CWriteReg8(fd_SH1106, control, 0x22); // internal VCC: 0xF1 | external VCC: 0x22
    wiringPiI2CWriteReg8(fd_SH1106, control, SH1106_SETVCOMDETECT);
    wiringPiI2CWriteReg8(fd_SH1106, control, 0x20);

    wiringPiI2CWriteReg8(fd_SH1106, control, SH1106_DISPLAYALLON_RESUME);
    wiringPiI2CWriteReg8(fd_SH1106, control, SH1106_NORMALDISPLAY);

    wiringPiI2CWriteReg8(fd_SH1106, control, SH1106_DISPLAYON); // Finally switch the display ON
}

void SH1106::sh1106_display(int fd_SH1106)
{
    for (unsigned short page = 0; page < 8; page++)
    {
        wiringPiI2CWriteReg8(fd_SH1106, control, 0x00);
        wiringPiI2CWriteReg8(fd_SH1106, control, 0x10);
        wiringPiI2CWriteReg8(fd_SH1106, control, 0xB0 | (page & 0x0F));

        for (int i = 0; i < 128; i++)
        {
            wiringPiI2CWriteReg8(fd_SH1106, 0x40, buffer[page * 128 + i]);
        }
    }
}

void SH1106::sh1106_clearDisplay(int fd_SH1106)
{
    memset(buffer, 0, (WIDTH * HEIGHT / 8) * sizeof(int));
    cursor_y = 0;
    cursor_x = 0;
}

void SH1106::sh1106_displayOFF(int fd_SH1106)
{
    sh1106_clearDisplay(fd_SH1106);
    wiringPiI2CWriteReg8(fd_SH1106, control, SH1106_DISPLAYOFF);
}

void SH1106::sh1106_drawPixel(int x, int y, unsigned int color)
{
    if ((x < 0) || (x >= WIDTH) || (y < 0) || (y >= HEIGHT))
    {
        runtime_error("Pixels out of bounds");
    }
    // Check rotation - Move pixel if necessary
    switch (rotation)
    {
    case 1:
        sh1106_swap(x, y);
        x = WIDTH - x - 1;
        break;
    case 2:
        x = WIDTH - x - 1;
        y = HEIGHT - y - 1;
        break;
    case 3:
        sh1106_swap(x, y);
        y = HEIGHT - y - 1;
        break;
    }
    // Check which column x is
    switch (color)
    {
    case WHITE:
        buffer[x + (y / 8) * WIDTH] |= (1 << (y & 7));
        break;
    case BLACK:
        buffer[x + (y / 8) * WIDTH] &= ~(1 << (y & 7));
        break;
    case INVERSE:
        buffer[x + (y / 8) * WIDTH] ^= (1 << (y & 7));
        break;
    }
}

void SH1106::sh1106_write(int c)
{
    if (c == '\n')
    {
        cursor_y += textsize * 8;
        cursor_x = 0;
    }
    else if (c == '\r')
    {
        // do nothing
    }
    else
    {
        sh1106_drawChar(cursor_x, cursor_y, c, WHITE, textsize);
        cursor_x += textsize * 6;
        if (wrap && (cursor_x > (WIDTH - textsize * 6)))
        {
            cursor_y += textsize * 8;
            cursor_x = 0;
        }
    }
}

void SH1106::sh1106_drawString(string str)
{
    int i, len;
    len = str.length();
    for (i = 0; i < len; i++)
    {
        sh1106_write(str[i]);
    }
}

void SH1106::sh1106_drawChar(int x, int y, unsigned char c, int color, int size)
{
    if ((x >= WIDTH) ||             // Clip right
        (y >= HEIGHT) ||            // Clip bottom
        ((x + 6 * size - 1) < 0) || // Clip left
        ((y + 8 * size - 1) < 0))   // Clip top
        return;
    int i, j;
    for (i = 0; i < 6; i++)
    {
        int line;
        if (i == 5)
            line = 0x0;
        else
            line = pgm_read_byte(font + (c * 5) + i);
        for (j = 0; j < 8; j++)
        {
            if (line & 0x1)
                sh1106_drawPixel(x + i, y + j, color);
            line >>= 1;
        }
    }
}

string SH1106::getDateTime(int date_or_time)
{
    // Can add additional formats in the future
    time_t timeStamp = time(0);
    string dt = ctime(&timeStamp);
    istringstream iss(dt);

    vector<string> date_buffer;
    copy(istream_iterator<string>(iss),
         istream_iterator<string>(),
         back_inserter(date_buffer));
    ostringstream dateToFormat;
    dateToFormat << date_buffer[2] << " " << date_buffer[1] << " " << date_buffer[4];

    switch (date_or_time)
    {
    case 0:
        return dateToFormat.str();
    case 1:
        return date_buffer[3];
    };

    return 0;
}

void SH1106::sh1106_displayData(int fd_SH1106, int t, int p, int h, int lux)
{
    sh1106_clearDisplay(fd_SH1106);
    string formatted_date = getDateTime(DATE);
    string formatted_time = getDateTime(TIME);

    ostringstream sensorData;
    sensorData << " Date:" << formatted_date << "\n Time:" << formatted_time << "\n"
               << " --------------------\n"
               << " " << round(t * 10) / 10 << " C | " << round(p * 10) / 10 << "hPa\n" // will need to add rounding functions
               << " --------------------\n"
               << " " << round(h * 10) / 10 << "% | " << round(lux * 10) / 10 << "lux";
    string sensorDataOut = sensorData.str();
    sh1106_drawString(sensorDataOut);
    sh1106_display(fd_SH1106);
}

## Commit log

2020-01-29 Initial Pitch Presentation
    * Idea
    * Reasoning
    * Product Design Idea (prototype)
    * App Idea (Initial)
2020-02-27 Create ActivityMain.java
    Main activity controlling LEDs on raspberry pi.
2020-03-05 Initialise folder for manufacturing PCB
2020-03-11 Source Files v0.1
    [A2_Full_Schematic.SchDoc, Parts_Lib_SMAQ.SchLib, Pcb_Lib_SMAQ.PcbLib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]
2020-03-13 BME280 i2c connection successfully implemented & temp, pres, hum data extracted + data compiled into JSON format + CMakeLists.txt implemented. Use cmake . + make + ./BME280 to run
2020-03-14 Added STEP files for the 3D components library
    [30Pin.SLDPRT, 40Pin.STEP, CircuitWorks-SOD123.step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]
2020-03-15 added i2c config for VCNL4010, unit test added for i2c communication
2020-03-16 Added ADS1115 for microphone & gas sensor
2020-03-16 bug in code - debug!
    [BME280.cpp]
2020-03-16 SH1106 I2C interface implemented
2020-03-17 Bug fixes for sh1106 display
    [BME280.cpp]
2020-03-25 init commit - added csv for plots
    [ambient.csv, gas.csv, hum.csv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]
2020-03-25 Create Readme for Gerber Files
2020-03-25 transmits comma seperated text from the sensors now
2020-03-25 Create Drill Output Readme
2020-03-25 Rename Hardware/PCB Manufacturing/NC Drill Output/ReadmeDrillOutput.md to Hardware/PCB Manufacturing/NC Drill Output/NC Drill Output/ReadmeDrillOutput.md
2020-03-25 Rename Hardware/PCB Manufacturing/NC Drill Output/NC Drill Output/ReadmeDrillOutput.md to Hardware/PCB Manufacturing/NC Drill Output/NC Drill OutputReadmeDrillOutput.md
2020-03-25 Add Drill Files for Manufacturing incl. PDF
2020-03-27 Source files v1.0
    [A2_Full_Schematic.SchDoc, Parts_Lib_SMAQ.SchLib]
2020-03-27 Add Project Logs
    Add Project Logs with change history for the Board Design
2020-03-27 Add files for PCB etching in UofG
2020-03-28 Title row not needed
    [ambient.csv, gas.csv, hum.csv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]
2020-03-28 Create readme file for board assembly
2020-03-28 Add Bill of Materials
    [SMAQ-Board_DesignBOM.xlsx]
2020-03-30 updated writetoCSV, data shift
    [api.csv]
2020-03-30 Add etched board images
2020-03-30 Add board images
2020-03-30 Add Prototype images
2020-03-30 added auto-zoom buttons
2020-04-01 implemented alerts (todo:delete and refresh alerts)
    [api.csv]
2020-04-02 Updated alert handler
    [api.csv]
2020-04-04 Added config.env
    [api.csv]
2020-04-04 minor changes
    [api.csv]
2020-04-07 styling chages
    [api.csv]
2020-04-07 example config.env file
    [example-config.env.txt]
2020-04-07 Sendgrid setup changed
    [example-config.env.txt]
2020-04-07 WebApp style changes
    [api.csv]
2020-04-07 added multiple input compatibility
    [api.csv]
2020-04-08 styling changes
    [api.csv]
2020-04-10 added npm run start:host for hosting using real email but fake data
    [api.csv]
2020-04-11 Update Schematic Picture for 1.1V
2020-04-13 Modified htmls for the Android app
    [api.csv]
2020-04-13 Update to v1.1
    [A2_Full_Schematic.SchDoc]
2020-04-13 Update to v1.1 - Add individual schematics
    [[1] - Layout Information.SchDoc, [2] - Header and I2C.SchDoc, [3] - Gas Sensor and ADC.SchDoc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]
2020-04-13 Add Simplified Assembly Drawings
2020-04-14 Add Printable A4 Schematics
2020-04-14 Add Full A2 SChematics
2020-04-16 Add Final Board Image
